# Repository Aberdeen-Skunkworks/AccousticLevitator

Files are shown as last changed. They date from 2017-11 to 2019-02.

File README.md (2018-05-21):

# Accoustic Levitator

A device for trapping and manipulating particles in three dimensions as well as the software to simulate these traps.

This Project is split into two distinct sections (1) The control software for the physical array, (2) The acoustic simulation to model the fields produced by this array.

The goal is to have a system that can self-calibrate where the control software can detect and automatically figure out where multiple acoustic arrays are in relation to each other, (Using the -> Aberdeen-Skunkworks/AccousticTracker project) It can then take this positional information and form acoustic traps at desired locations.

The files in the /eagle folder are PCB design files that use the Autodesk PCB design software Eagle which can be found here: https://www.autodesk.com/products/eagle/overview

The files in the /FPGA folder are the setup files that are running on the Field-Programable Gate Arrays that create the ultrasonic signals that are sent to the transducers.

# (1) Control software

# (2) Acoustic simulation

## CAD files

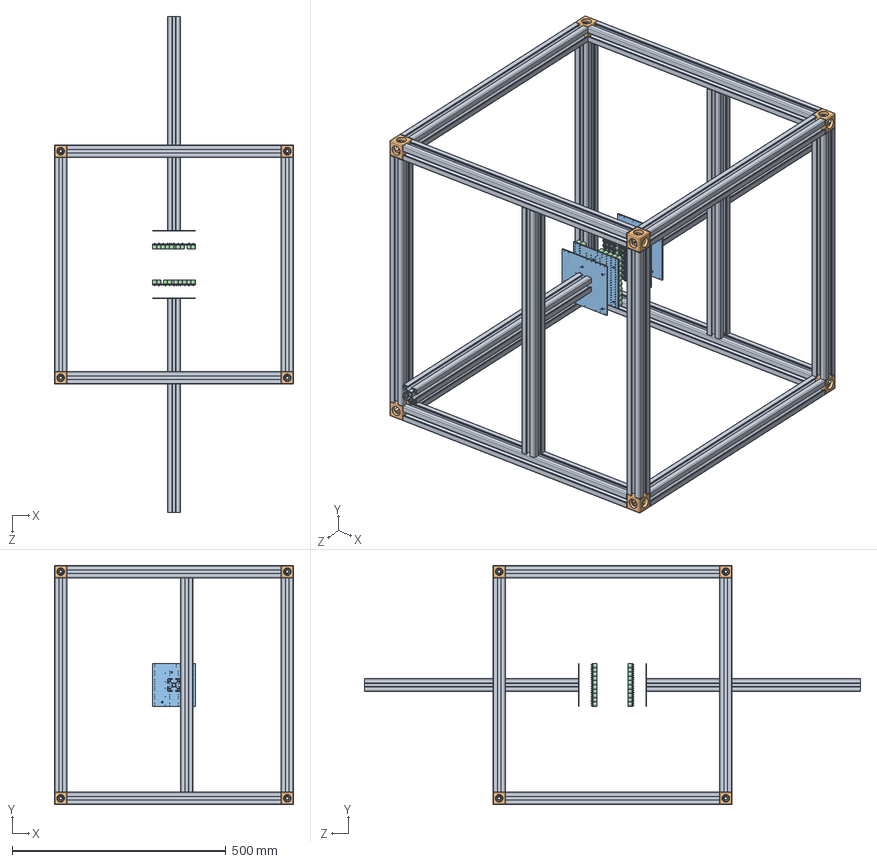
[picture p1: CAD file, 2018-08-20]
Moddeling_Files/Assembly of frame.SLDASM
560.0 x 560.0 x 1160.0 mm
30 mm al profile x 16
corner x 8
board x 4
Transducer x 176

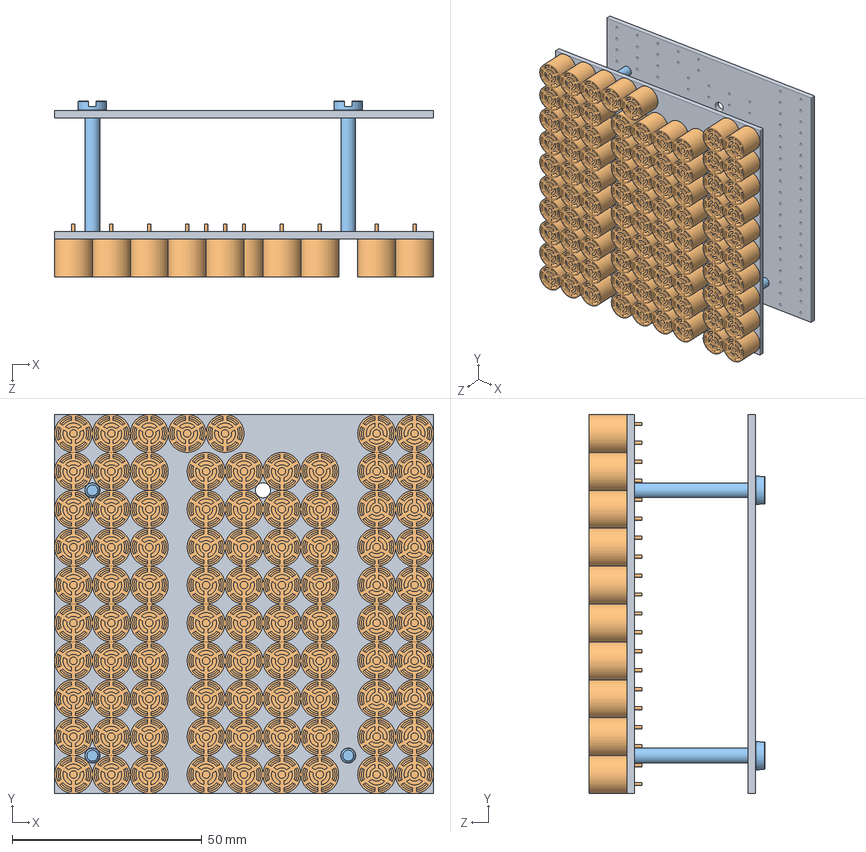
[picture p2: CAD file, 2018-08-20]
Moddeling_Files/Board and transducers.SLDASM
100.0 x 100.0 x 46.5 mm
board x 2
Transducer x 88
bolt x 3

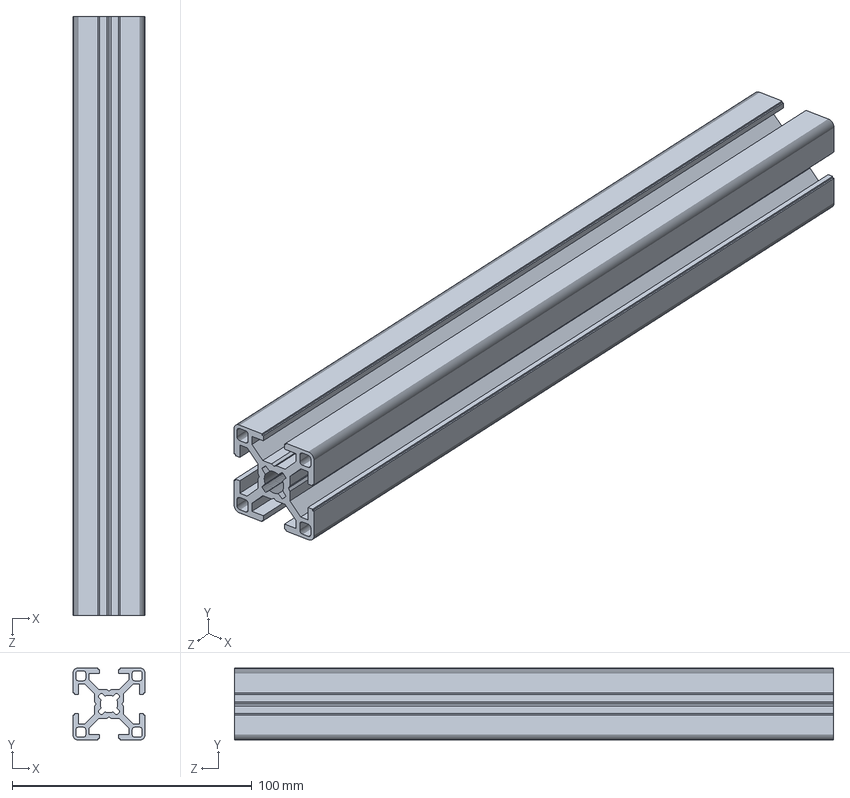
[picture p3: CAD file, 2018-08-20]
Moddeling_Files/Accurate 30 mm profile.SLDPRT
30.0 x 30.0 x 250.0 mm

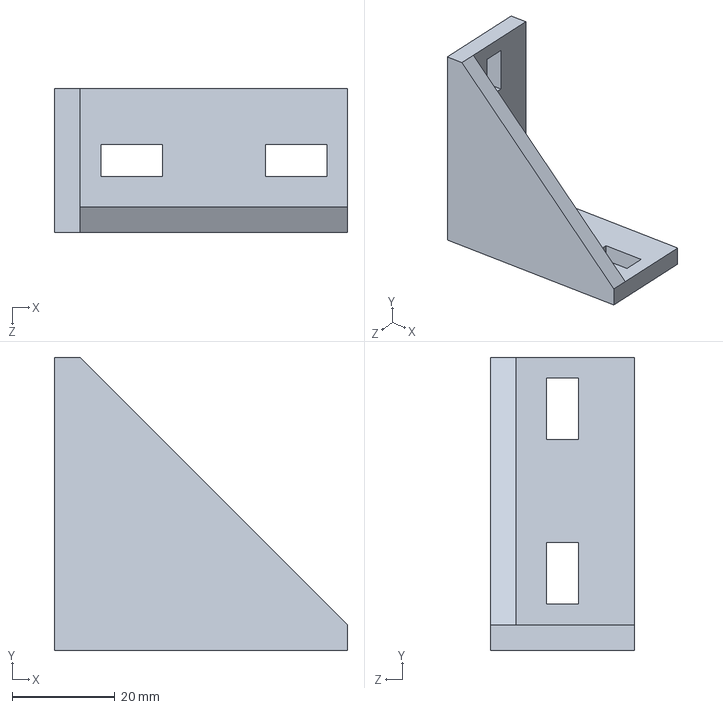
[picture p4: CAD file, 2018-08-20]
Moddeling_Files/angle bracket.SLDPRT
57.0 x 57.0 x 28.0 mm

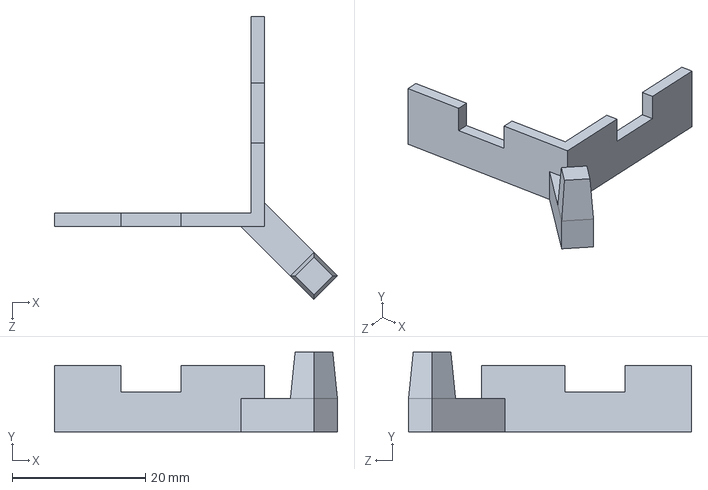
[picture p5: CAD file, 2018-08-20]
Moddeling_Files/hook2.SLDPRT
42.5 x 12.0 x 42.5 mm

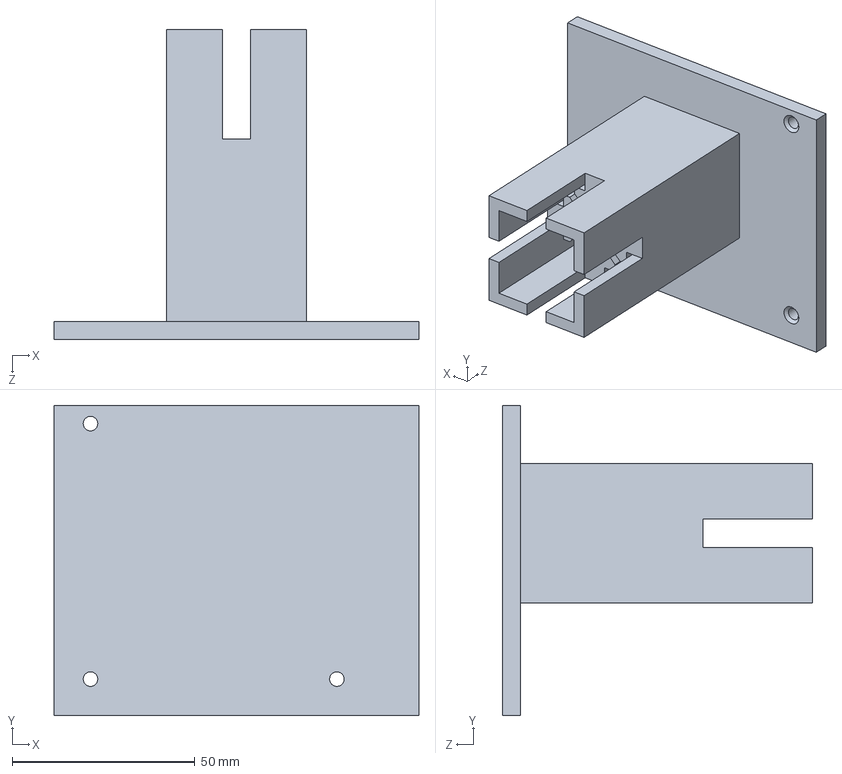
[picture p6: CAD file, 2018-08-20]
Moddeling_Files/board holder no tubes and thicker back.SLDPRT
100.0 x 85.0 x 85.0 mm

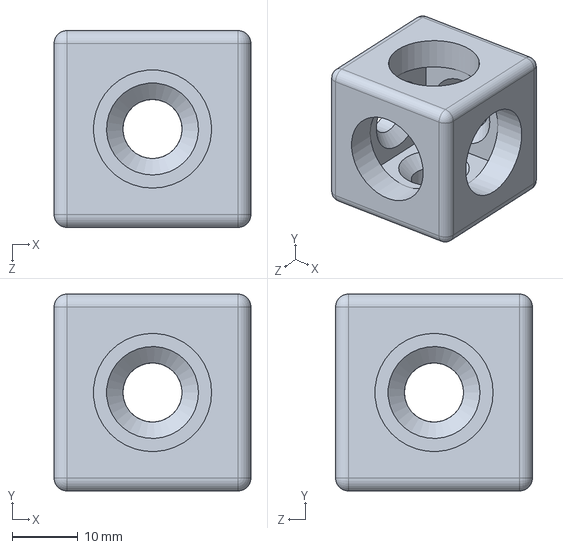
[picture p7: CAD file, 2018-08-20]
Moddeling_Files/corner.SLDPRT
30.0 x 30.0 x 30.0 mm

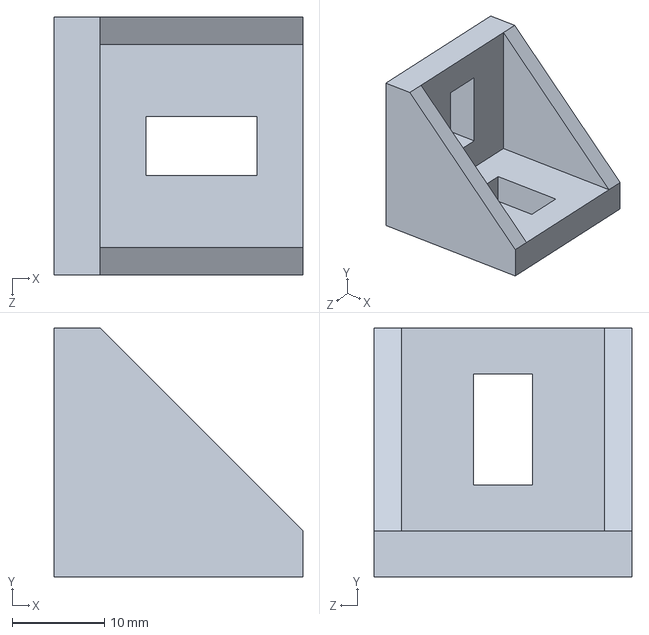
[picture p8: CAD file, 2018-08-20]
Moddeling_Files/corner_small.SLDPRT
27.0 x 27.0 x 28.0 mm

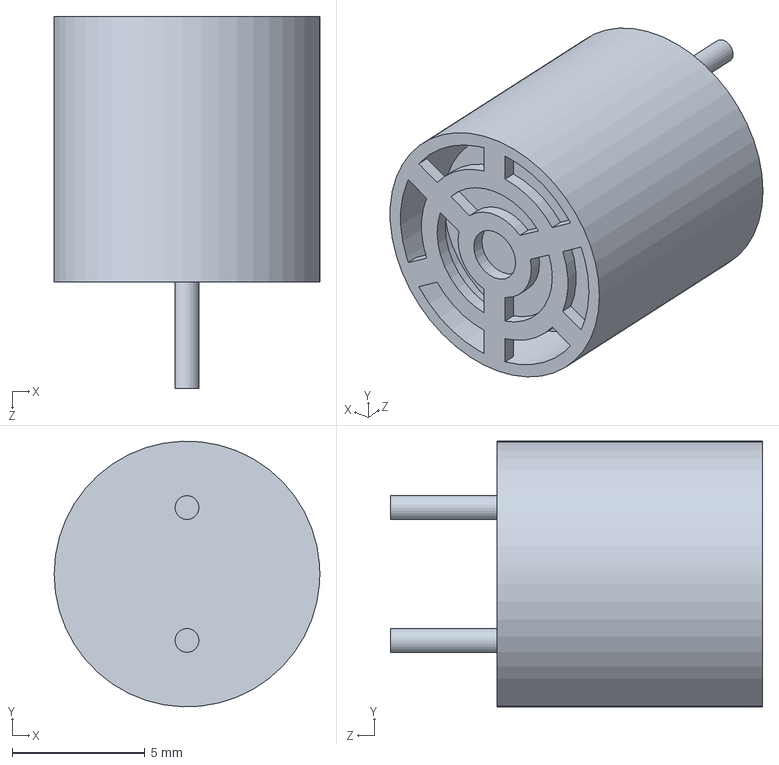
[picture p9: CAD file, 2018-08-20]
Moddeling_Files/Transducer.SLDPRT
10.0 x 9.99 x 14.0 mm

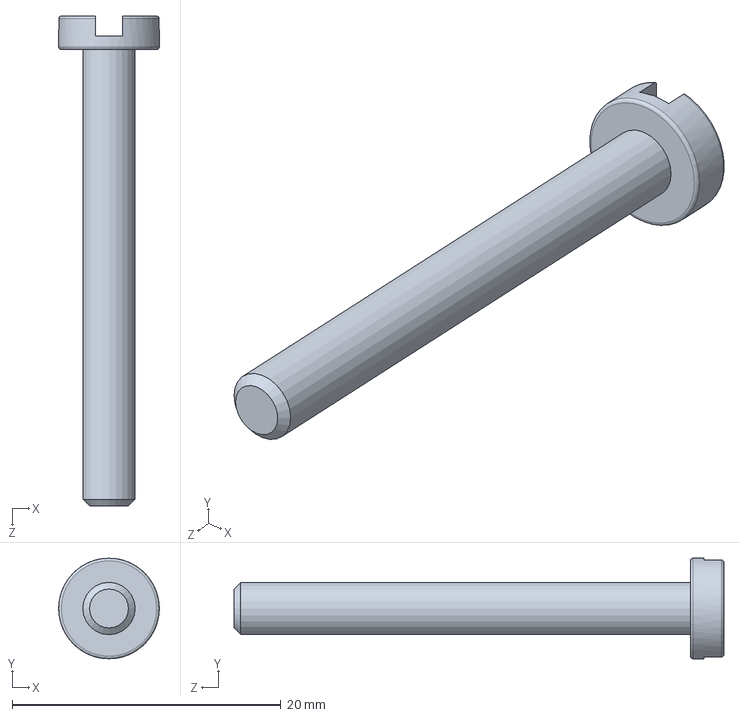
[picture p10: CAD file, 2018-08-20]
Moddeling_Files/bolt.SLDPRT
7.50 x 7.50 x 36.5 mm

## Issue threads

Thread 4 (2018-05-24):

Thread for Minor Syntax Problems

FourierSoiXa, 2018-05-24:
Hi guys,

I'd like to simply divide two numbers in Python 2.7 and get a 'double' output result,
float(A/B) does not seem to work, can someone point me into the right direction :)

Thanks, Fabio

toastedcrumpets, 2018-05-24:
If the numbers are integers, then you only get integer results from the
division. Promote one of them to float first i.e. float(a)/b or (a+0.0)/b
if you want to be obscure.

BTW, python 3 and later automatically promotes them when a integer divide
would lose information via truncation

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

FourierSoiXa, 2018-05-24:
That's great thanks! It works just fine like that:

`print 'The tested Number is a ' + str(tIndex) + ' with a probability of ' + str(float(tCount)/nPerfectMatch)`

Just working on recognizing some numbers and I'll try to get shapes done by the weekend. Files will be uploaded as soon as they are completed and commented

toastedcrumpets, 2018-05-24:
Great! Remember useful python commands like type(X) repr(X) and help(X).
Also, try dir(X) on objects too.

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

FourierSoiXa, 2018-05-27:
A little help is required with the return statements of functions:
I'd like to calculate the center of an image and return the respective x and y coordinates to be used in different functions and the function seems to work just fine:

`def centerImage(filePath):
    iCenter = Image.open(filePath)
    iArray = iCenter.load()
    iDisplay = np.array(iCenter)
    (X,Y) = iCenter.size
    matrix = np.zeros((X,Y))
    # Create a matrix containing 1's for every pixel of the image
    for x in range(X):
        for y in range(X):
            matrix[x,y] = iArray[(x,y)] != (255,255,255)
    matrix = matrix/np.sum(np.sum(matrix))

    # Compute marginal distribution and expected values

    dx = np.sum(matrix,1)
    dy = np.sum(matrix,0)

    expX = np.sum(dx*np.arange(X))
    expY = np.sum(dy*np.arange(Y))

    # Displays Examples of the center of the image

    fig = plt.figure()
    plt.imshow(iDisplay)
    plt.plot(expX, expY, marker='s', linestyle='-', color='r')
    plt.show()
    return [expX,expY] `

For some reason I can't make the return statement work/ cannot assign the returned values to a new variable. I tired:

`comX = centerImage
comX = centerImage[0]
print comX(0)`

Help would be greatly appreciated :) Thanks a lot in advance

NiallMacD, 2018-05-27:
Not entirely sure what your code is doing or supposed to do. Firstly I am assuming when you loop over x and y that "for y in range(X):" should be "for y in range(Y):". Other than that see below how you call your function while passing it "1 required positional argument: 'filePath' " making a variable equal to the called function will set that variable to whatever is returned by that function.
Hope this helps, if you could explain what its trying to do that would be ace, i tried it with a blank image and it set a random square of it red in the output.

```ruby
import numpy as np
from PIL import Image
import matplotlib.pyplot as plt

def centerImage(filePath):
    iCenter = Image.open(filePath)
    iArray = iCenter.load()
    iDisplay = np.array(iCenter)
    (X,Y) = iCenter.size
    matrix = np.zeros((X,Y))

    # Create a matrix containing 1's for every pixel of the image
    for x in range(X):
        for y in range(Y):
            matrix[x,y] = iArray[(x,y)] != (255,255,255)
            matrix = matrix/np.sum(np.sum(matrix))

    # Compute marginal distribution and expected values

    dx = np.sum(matrix,1)
    dy = np.sum(matrix,0)

    expX = np.sum(dx*np.arange(X))
    expY = np.sum(dy*np.arange(Y))

    # Displays Examples of the center of the image

    fig = plt.figure()
    plt.imshow(iDisplay)
    plt.plot(expX, expY, marker='s', linestyle='-', color='r')
    plt.show()
    return [expX,expY]

# Pass the function the location of the test image
where_you_want_output_to_go = centerImage( "test_image.png" )

# print the x, y co-ordinates
print(where_you_want_output_to_go)

```

FourierSoiXa, 2018-05-27:
Hi Niall,
aaaaw that makes perfect sense.... whenever I tried to assign the returned values to a variable I didnt actually include the filePath argument. I guess I've been staring at the screen for a little too long.

Sorry for not including the import statements, that would have made it a little more clear.
The function is computing the center of the image based on the distribution of non-white pixels. I tried to recognize numbers with a program I'm working on but the problem I faced was that, as soon as the number was a little displaced, my program would predict a completely different number.
That's why I want to center the image first. Maybe the next task would be including rotation etc but just now I'm far away from that.

Try another image that is not entirely symetrical :) I'll upload a fully commented code in a day or two into the particle recognition thread, just now I'm not even sure whether the stuff I wrote is actually working.

Thanks a lot :)

toastedcrumpets, 2018-05-28:
With return statements and multiple values, you can do this (which is a bit neater)
`
def f():
  return 1,2,3,4
a,b,c,d = f()
 `
This returns the values as a tuple rather than a list. They work the same, but in theory a tuple is faster as its a fixed size.

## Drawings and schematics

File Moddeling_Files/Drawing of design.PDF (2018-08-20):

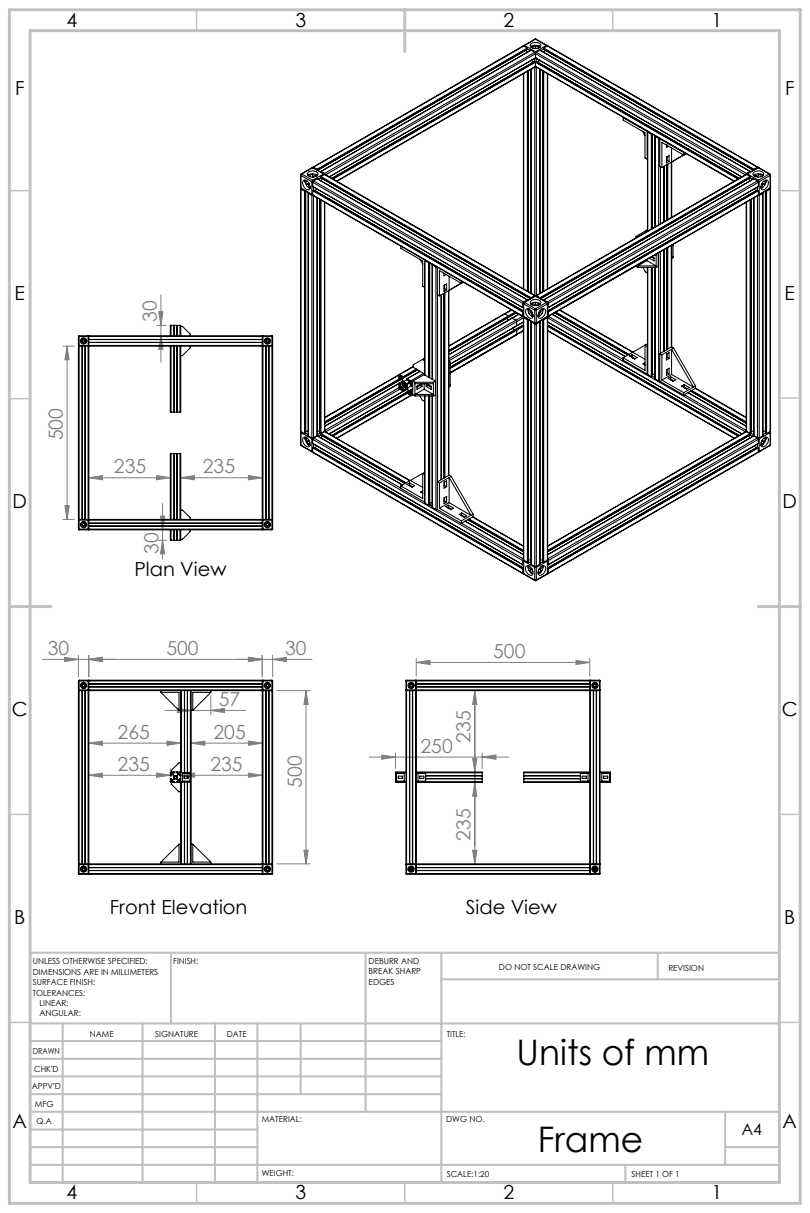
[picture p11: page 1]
Front Elevation; Side View; Plan View; FINISH:; DEBURR AND; BREAK SHARP; DO NOT SCALE DRAWING; REVISION; SCALE:1:20; SHEET 1 OF 1

UNLESS OTHERWISE SPECIFIED:
DIMENSIONS ARE IN MILLIMETERS
SURFACE FINISH:
TOLERANCES:
LINEAR:
ANGULAR:

NAME | SIGNATURE | DATE | | | | TITLE: Units of mm

DRAWN
CHK'D
APPV'D
MFG
Q.A | | | | MATERIAL: | DWG NO. Frame | A4

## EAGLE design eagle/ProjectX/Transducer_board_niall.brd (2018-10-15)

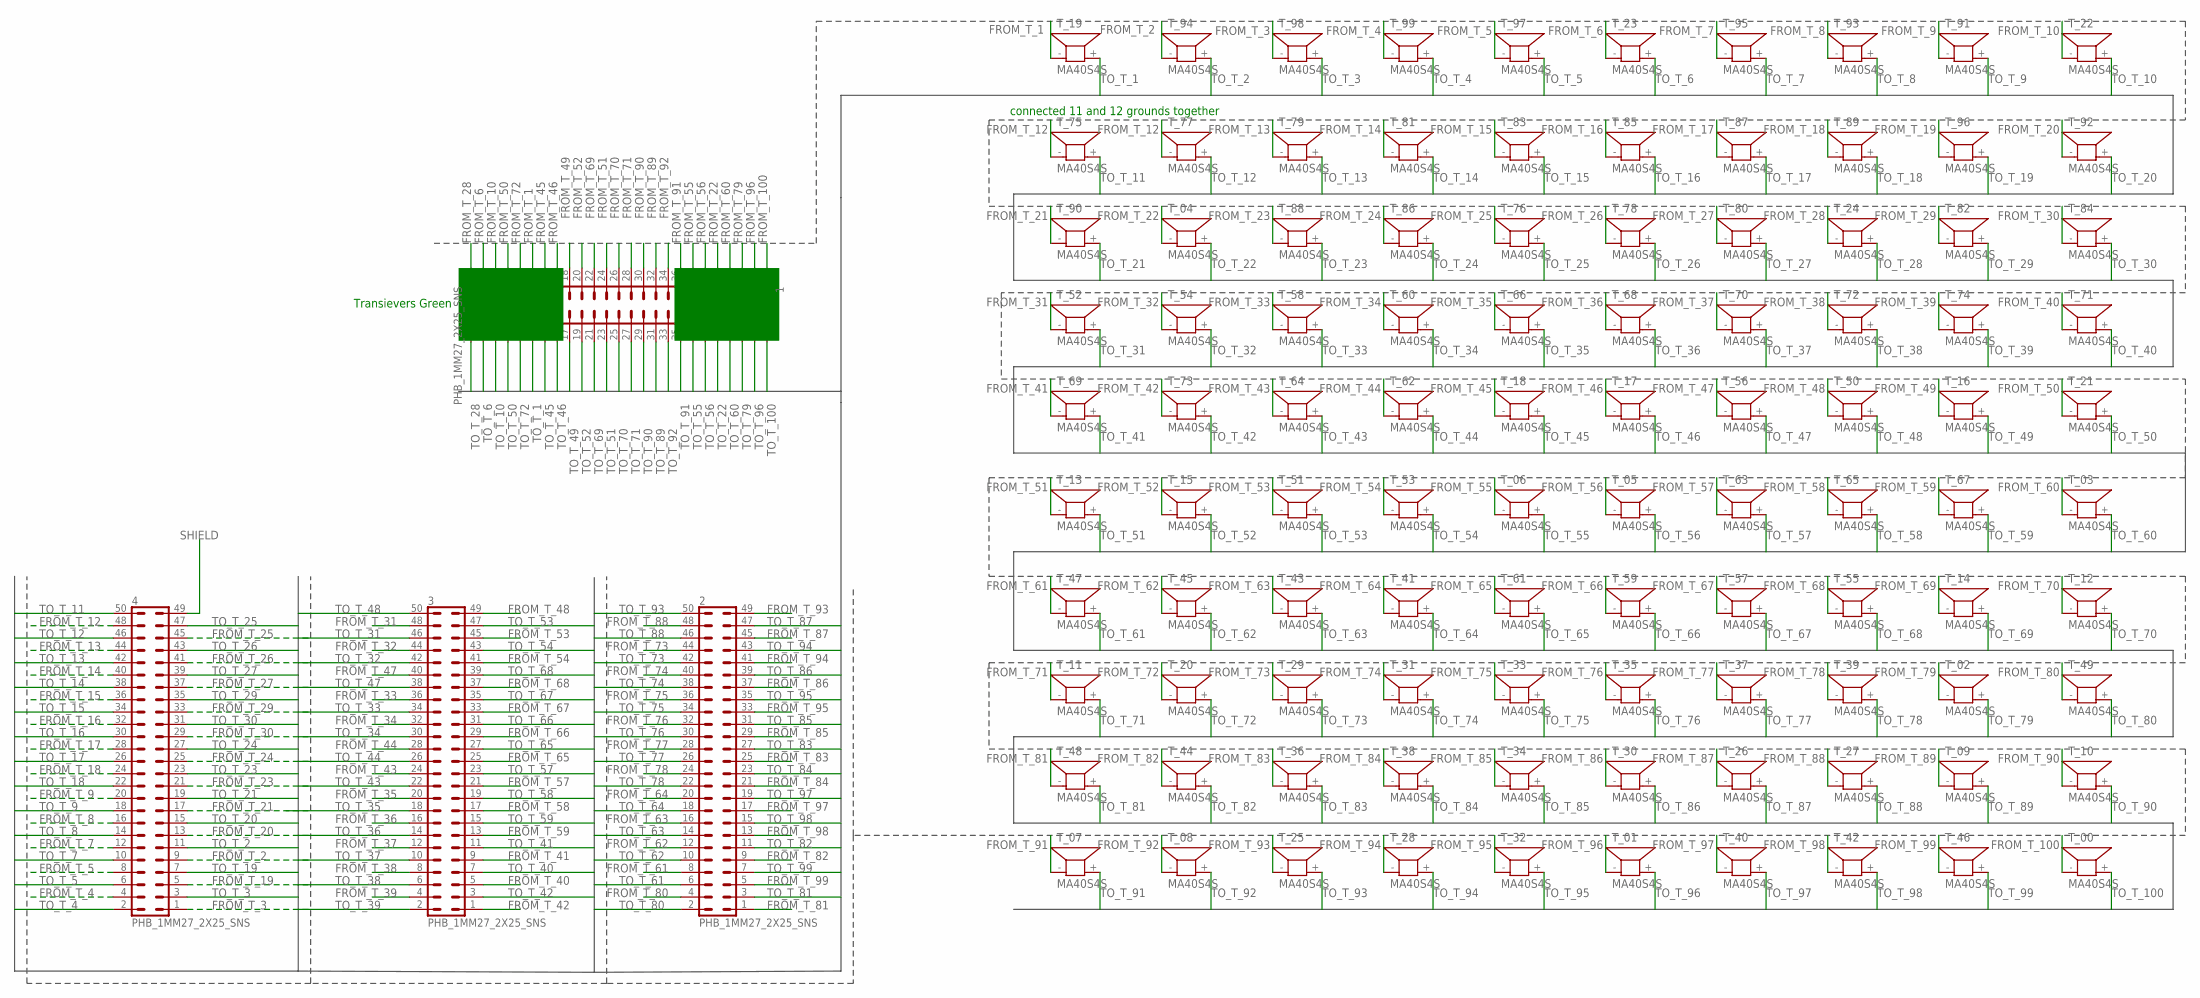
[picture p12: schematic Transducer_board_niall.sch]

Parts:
1, 2, 3, 4: PHB_1MM27_2X25_SNS
T_00, T_01, T_02, T_03, T_04, T_05, T_06, T_07, T_08, T_09, T_10, T_11, T_12, T_13, T_14, T_15, T_16, T_17, T_18, T_19, T_20, T_21, T_22, T_23, T_24, T_25, T_26, T_27, T_28, T_29, T_30, T_31, T_32, T_33, T_34, T_35, T_36, T_37, T_38, T_39, T_40, T_41, T_42, T_43, T_44, T_45, T_46, T_47, T_48, T_49, T_50, T_51, T_52, T_53, T_54, T_55, T_56, T_57, T_58, T_59, T_60, T_61, T_62, T_63, T_64, T_65, T_66, T_67, T_68, T_69, T_70, T_71, T_72, T_73, T_74, T_75, T_76, T_77, T_78, T_79, T_80, T_81, T_82, T_83, T_84, T_85, T_86, T_87, T_88, T_89, T_90, T_91, T_92, T_93, T_94, T_95, T_96, T_97, T_98, T_99: MA40S4S; MA40

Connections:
FROM_T_1: 1.12, T_19.- (1)
FROM_T_2: 4.9, T_94.- (1)
FROM_T_3: 4.1, T_98.- (1)
FROM_T_4: 4.4, T_99.- (1)
FROM_T_5: 4.8, T_97.- (1)
FROM_T_6: 1.4, T_23.- (1)
FROM_T_7: 4.12, T_95.- (1)
FROM_T_8: 4.16, T_93.- (1)
FROM_T_9: 4.20, T_91.- (1)
FROM_T_10: 1.6, T_22.- (1)
FROM_T_12: 4.48, T_75.- (1), T_77.- (1)
FROM_T_13: 4.44, T_79.- (1)
FROM_T_14: 4.40, T_81.- (1)
FROM_T_15: 4.36, T_83.- (1)
FROM_T_16: 4.32, T_85.- (1)
FROM_T_17: 4.28, T_87.- (1)
FROM_T_18: 4.24, T_89.- (1)
FROM_T_19: 4.5, T_96.- (1)
FROM_T_20: 4.13, T_92.- (1)
FROM_T_21: 4.17, T_90.- (1)
FROM_T_22: 1.42, T_04.- (1)
FROM_T_23: 4.21, T_88.- (1)
FROM_T_24: 4.25, T_86.- (1)
FROM_T_25: 4.45, T_76.- (1)
FROM_T_26: 4.41, T_78.- (1)
FROM_T_27: 4.37, T_80.- (1)
FROM_T_28: 1.2, T_24.- (1)
FROM_T_29: 4.33, T_82.- (1)
FROM_T_30: 4.29, T_84.- (1)
FROM_T_31: 3.48, T_52.- (1)
FROM_T_32: 3.44, T_54.- (1)
FROM_T_33: 3.36, T_58.- (1)
FROM_T_34: 3.32, T_60.- (1)
FROM_T_35: 3.20, T_66.- (1)
FROM_T_36: 3.16, T_68.- (1)
FROM_T_37: 3.12, T_70.- (1)
FROM_T_38: 3.8, T_72.- (1)
FROM_T_39: 3.4, T_74.- (1)
FROM_T_40: 3.5, T_71.- (1)
FROM_T_41: 3.9, T_69.- (1)
FROM_T_42: 3.1, T_73.- (1)
FROM_T_43: 3.24, T_64.- (1)
FROM_T_44: 3.28, T_62.- (1)
FROM_T_45: 1.14, T_18.- (1)
FROM_T_46: 1.16, T_17.- (1)
FROM_T_47: 3.40, T_56.- (1)
FROM_T_48: 3.49, T_50.- (1)
FROM_T_49: 1.18, T_16.- (1)
FROM_T_50: 1.8, T_21.- (1)
FROM_T_51: 1.24, T_13.- (1)
FROM_T_52: 1.20, T_15.- (1)
FROM_T_53: 3.45, T_51.- (1)
FROM_T_54: 3.41, T_53.- (1)
FROM_T_55: 1.38, T_06.- (1)
FROM_T_56: 1.40, T_05.- (1)
FROM_T_57: 3.21, T_63.- (1)
FROM_T_58: 3.17, T_65.- (1)
FROM_T_59: 3.13, T_67.- (1)
FROM_T_60: 1.44, T_03.- (1)
FROM_T_61: 2.8, T_47.- (1)
FROM_T_62: 2.12, T_45.- (1)
FROM_T_63: 2.16, T_43.- (1)
FROM_T_64: 2.20, T_41.- (1)
FROM_T_65: 3.25, T_61.- (1)
FROM_T_66: 3.29, T_59.- (1)
FROM_T_67: 3.33, T_57.- (1)
FROM_T_68: 3.37, T_55.- (1)
FROM_T_69: 1.22, T_14.- (1)
FROM_T_70: 1.26, T_12.- (1)
FROM_T_71: 1.28, T_11.- (1)
FROM_T_72: 1.10, T_20.- (1)
FROM_T_73: 2.44, T_29.- (1)
FROM_T_74: 2.40, T_31.- (1)
FROM_T_75: 2.36, T_33.- (1)
FROM_T_76: 2.32, T_35.- (1)
FROM_T_77: 2.28, T_37.- (1)
FROM_T_78: 2.24, T_39.- (1)
FROM_T_79: 1.46, T_02.- (1)
FROM_T_80: 2.4, T_49.- (1)
FROM_T_81: 2.1, T_48.- (1)
FROM_T_82: 2.9, T_44.- (1)
FROM_T_83: 2.25, T_36.- (1)
FROM_T_84: 2.21, T_38.- (1)
FROM_T_85: 2.29, T_34.- (1)
FROM_T_86: 2.37, T_30.- (1)
FROM_T_87: 2.45, T_26.- (1)
FROM_T_88: 2.48, T_27.- (1)
FROM_T_89: 1.32, T_09.- (1)
FROM_T_90: 1.30, T_10.- (1)
FROM_T_91: 1.36, T_07.- (1)
FROM_T_92: 1.34, T_08.- (1)
FROM_T_93: 2.49, T_25.- (1)
FROM_T_94: 2.41, T_28.- (1)
FROM_T_95: 2.33, T_32.- (1)
FROM_T_96: 1.48, T_01.- (1)
FROM_T_97: 2.17, T_40.- (1)
FROM_T_98: 2.13, T_42.- (1)
FROM_T_99: 2.5, T_46.- (1)
FROM_T_100: 1.50, T_00.- (1)
SHIELD: 4.49
TO_T_1: 1.11, T_19.+ (2)
TO_T_2: 4.11, T_94.+ (2)
TO_T_3: 4.3, T_98.+ (2)
TO_T_4: 4.2, T_99.+ (2)
TO_T_5: 4.6, T_97.+ (2)
TO_T_6: 1.3, T_23.+ (2)
TO_T_7: 4.10, T_95.+ (2)
TO_T_8: 4.14, T_93.+ (2)
TO_T_9: 4.18, T_91.+ (2)
TO_T_10: 1.5, T_22.+ (2)
TO_T_11: 4.50, T_75.+ (2)
TO_T_12: 4.46, T_77.+ (2)
TO_T_13: 4.42, T_79.+ (2)
TO_T_14: 4.38, T_81.+ (2)
TO_T_15: 4.34, T_83.+ (2)
TO_T_16: 4.30, T_85.+ (2)
TO_T_17: 4.26, T_87.+ (2)
TO_T_18: 4.22, T_89.+ (2)
TO_T_19: 4.7, T_96.+ (2)
TO_T_20: 4.15, T_92.+ (2)
TO_T_21: 4.19, T_90.+ (2)
TO_T_22: 1.41, T_04.+ (2)
TO_T_23: 4.23, T_88.+ (2)
TO_T_24: 4.27, T_86.+ (2)
TO_T_25: 4.47, T_76.+ (2)
TO_T_26: 4.43, T_78.+ (2)
TO_T_27: 4.39, T_80.+ (2)
TO_T_28: 1.1, T_24.+ (2)
TO_T_29: 4.35, T_82.+ (2)
TO_T_30: 4.31, T_84.+ (2)
TO_T_31: 3.46, T_52.+ (2)
TO_T_32: 3.42, T_54.+ (2)
TO_T_33: 3.34, T_58.+ (2)
TO_T_34: 3.30, T_60.+ (2)
TO_T_35: 3.18, T_66.+ (2)
TO_T_36: 3.14, T_68.+ (2)
TO_T_37: 3.10, T_70.+ (2)
TO_T_38: 3.6, T_72.+ (2)
TO_T_39: 3.2, T_74.+ (2)
TO_T_40: 3.7, T_71.+ (2)
TO_T_41: 3.11, T_69.+ (2)
TO_T_42: 3.3, T_73.+ (2)
TO_T_43: 3.22, T_64.+ (2)
TO_T_44: 3.26, T_62.+ (2)
TO_T_45: 1.13, T_18.+ (2)
TO_T_46: 1.15, T_17.+ (2)
TO_T_47: 3.38, T_56.+ (2)
TO_T_48: 3.50, T_50.+ (2)
TO_T_49: 1.17, T_16.+ (2)
TO_T_50: 1.7, T_21.+ (2)
TO_T_51: 1.23, T_13.+ (2)
TO_T_52: 1.19, T_15.+ (2)
TO_T_53: 3.47, T_51.+ (2)
TO_T_54: 3.43, T_53.+ (2)
TO_T_55: 1.37, T_06.+ (2)
TO_T_56: 1.39, T_05.+ (2)
TO_T_57: 3.23, T_63.+ (2)
TO_T_58: 3.19, T_65.+ (2)
TO_T_59: 3.15, T_67.+ (2)
TO_T_60: 1.43, T_03.+ (2)
TO_T_61: 2.6, T_47.+ (2)
TO_T_62: 2.10, T_45.+ (2)
TO_T_63: 2.14, T_43.+ (2)
TO_T_64: 2.18, T_41.+ (2)
TO_T_65: 3.27, T_61.+ (2)
TO_T_66: 3.31, T_59.+ (2)
TO_T_67: 3.35, T_57.+ (2)
TO_T_68: 3.39, T_55.+ (2)
TO_T_69: 1.21, T_14.+ (2)
TO_T_70: 1.25, T_12.+ (2)
TO_T_71: 1.27, T_11.+ (2)
TO_T_72: 1.9, T_20.+ (2)
TO_T_73: 2.42, T_29.+ (2)
TO_T_74: 2.38, T_31.+ (2)
TO_T_75: 2.34, T_33.+ (2)
TO_T_76: 2.30, T_35.+ (2)
TO_T_77: 2.26, T_37.+ (2)
TO_T_78: 2.22, T_39.+ (2)
TO_T_79: 1.45, T_02.+ (2)
TO_T_80: 2.2, T_49.+ (2)
TO_T_81: 2.3, T_48.+ (2)
TO_T_82: 2.11, T_44.+ (2)
TO_T_83: 2.27, T_36.+ (2)
TO_T_84: 2.23, T_38.+ (2)
TO_T_85: 2.31, T_34.+ (2)
TO_T_86: 2.39, T_30.+ (2)
TO_T_87: 2.47, T_26.+ (2)
TO_T_88: 2.46, T_27.+ (2)
TO_T_89: 1.31, T_09.+ (2)
TO_T_90: 1.29, T_10.+ (2)
TO_T_91: 1.35, T_07.+ (2)
TO_T_92: 1.33, T_08.+ (2)
TO_T_93: 2.50, T_25.+ (2)
TO_T_94: 2.43, T_28.+ (2)
TO_T_95: 2.35, T_32.+ (2)
TO_T_96: 1.47, T_01.+ (2)
TO_T_97: 2.19, T_40.+ (2)
TO_T_98: 2.15, T_42.+ (2)
TO_T_99: 2.7, T_46.+ (2)
TO_T_100: 1.49, T_00.+ (2)

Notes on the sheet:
Transievers Green
connected 11 and 12 grounds together

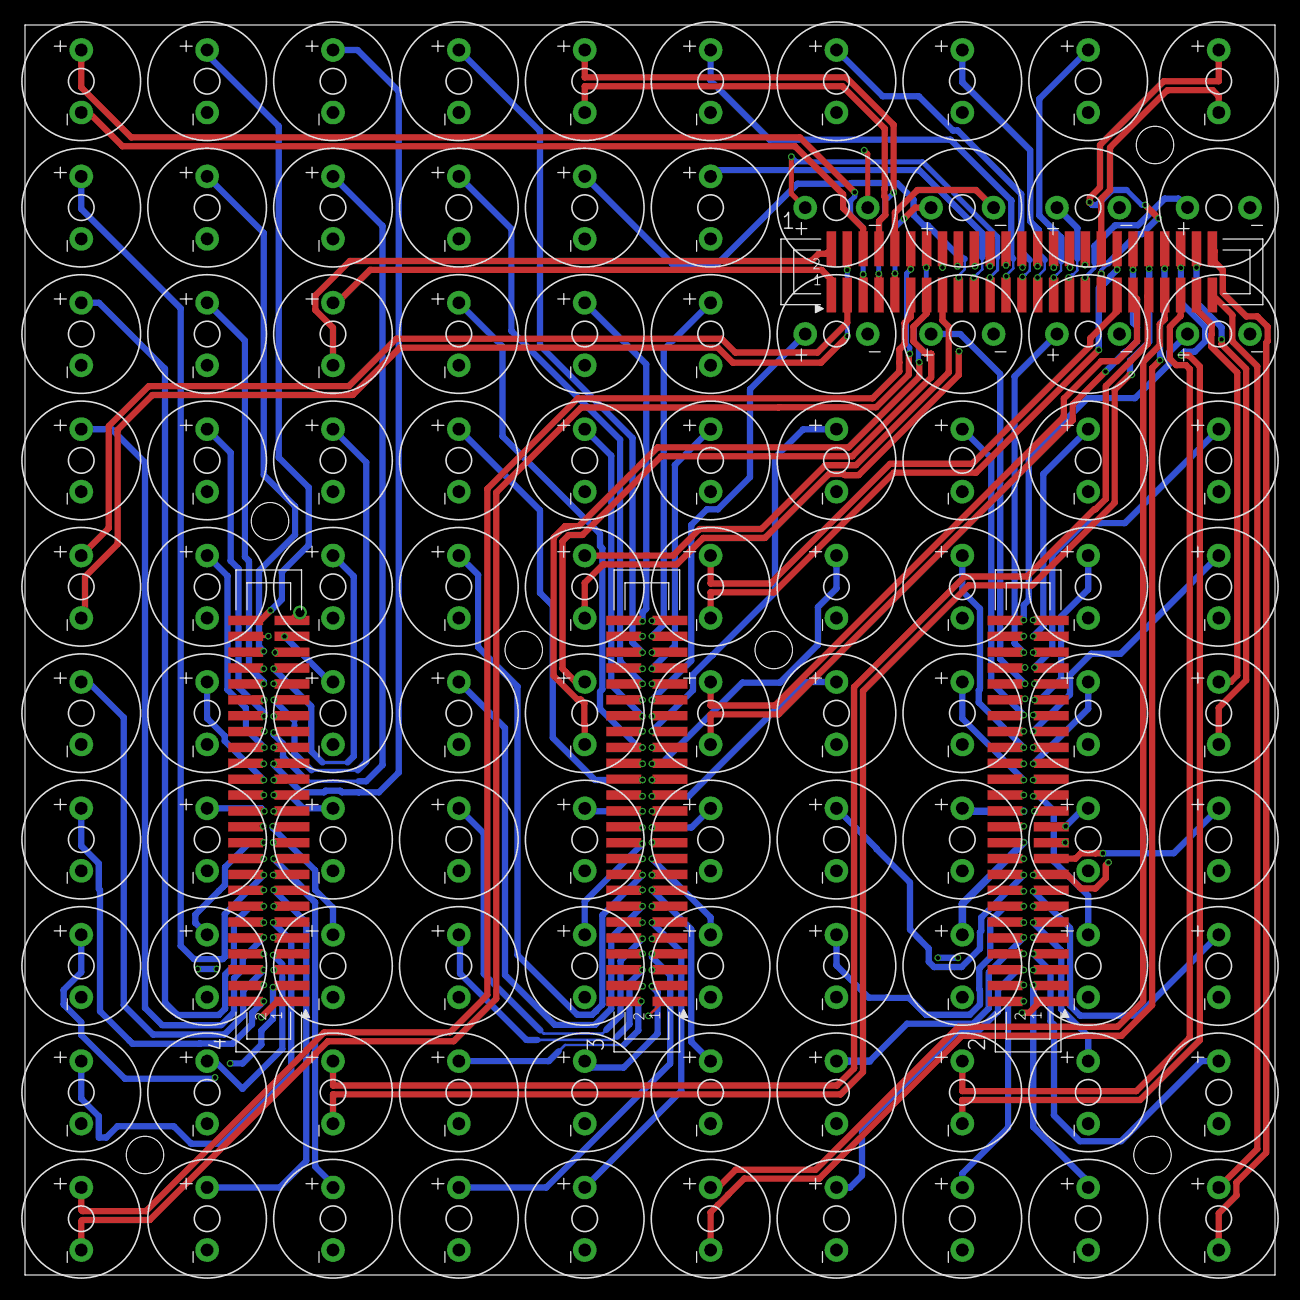
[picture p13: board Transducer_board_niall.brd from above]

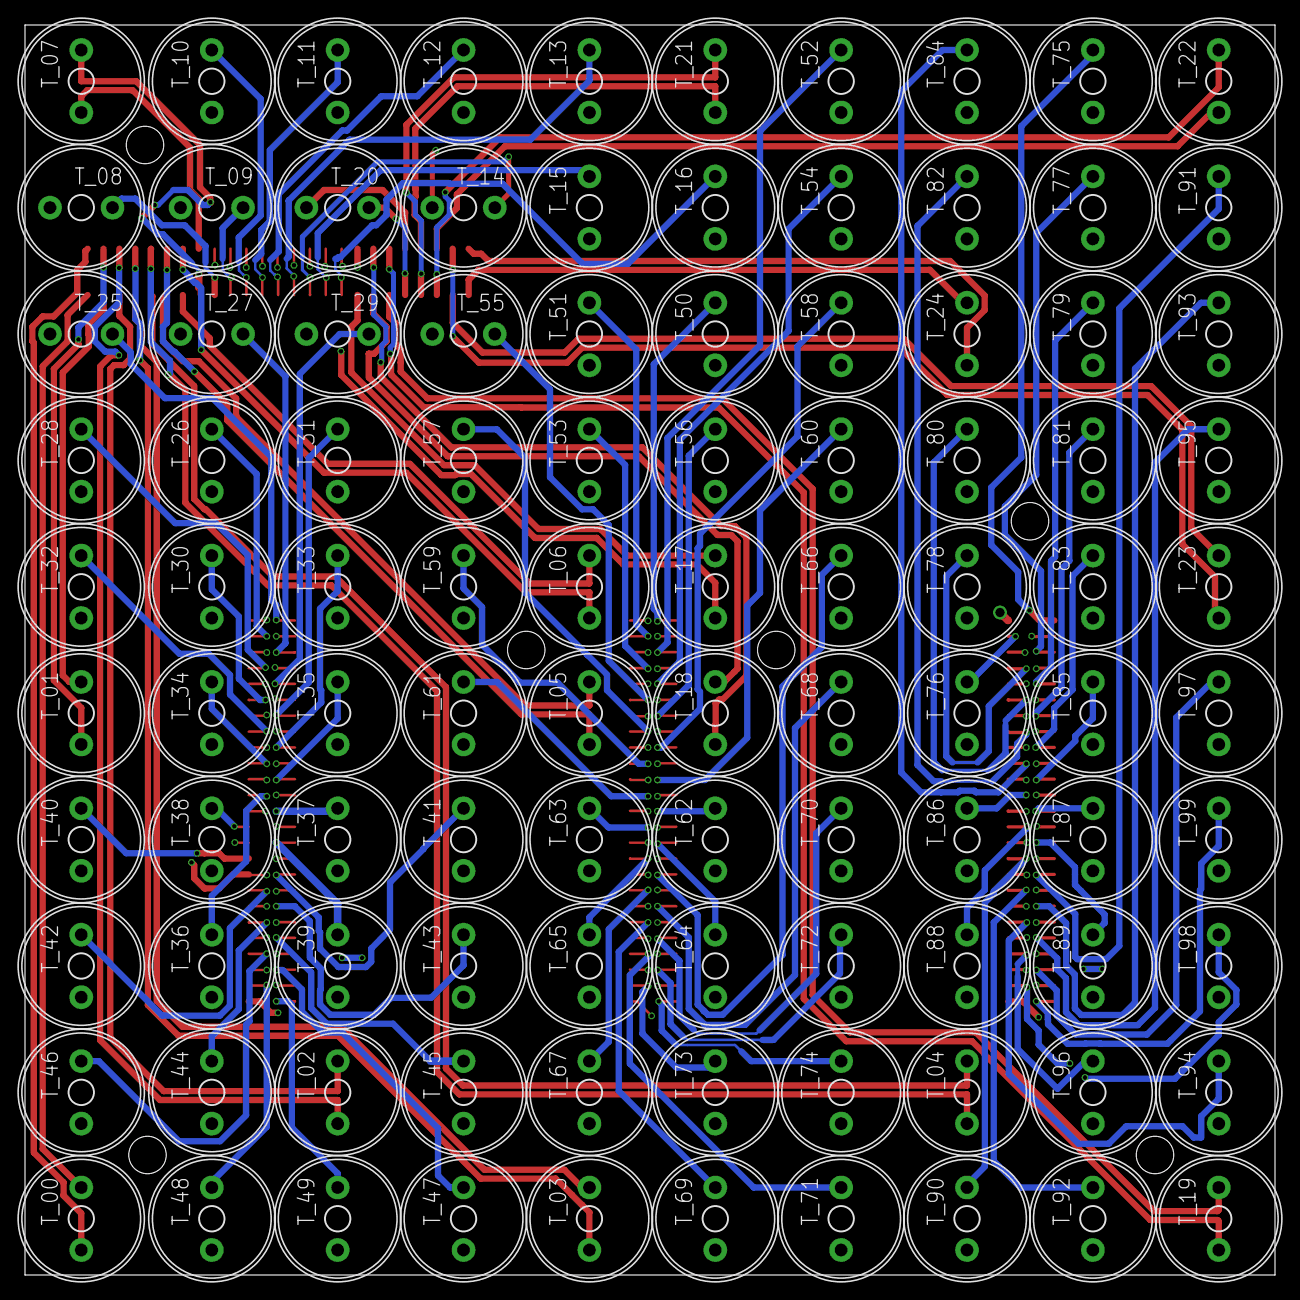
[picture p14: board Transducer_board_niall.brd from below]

Board: 4 copper layers, 100.0 x 100.0 mm, 104 parts (100 on the bottom side), 199 nets.

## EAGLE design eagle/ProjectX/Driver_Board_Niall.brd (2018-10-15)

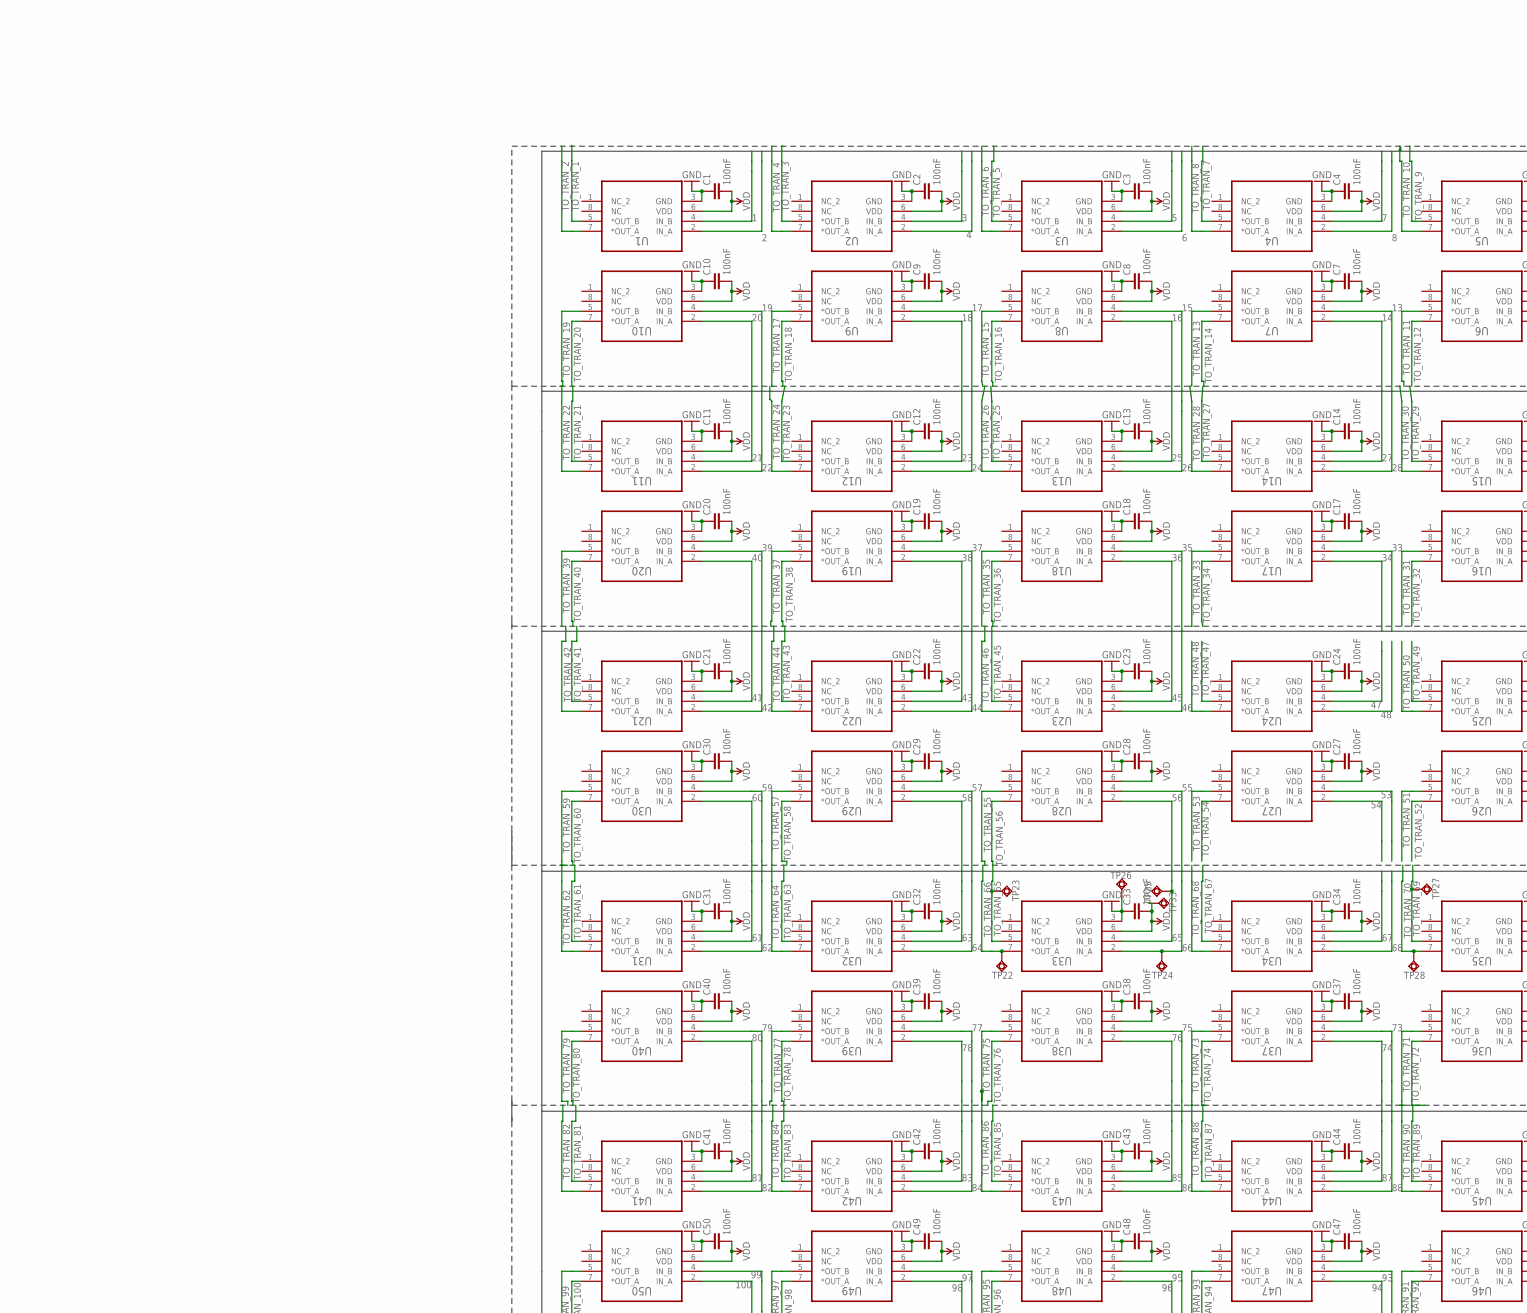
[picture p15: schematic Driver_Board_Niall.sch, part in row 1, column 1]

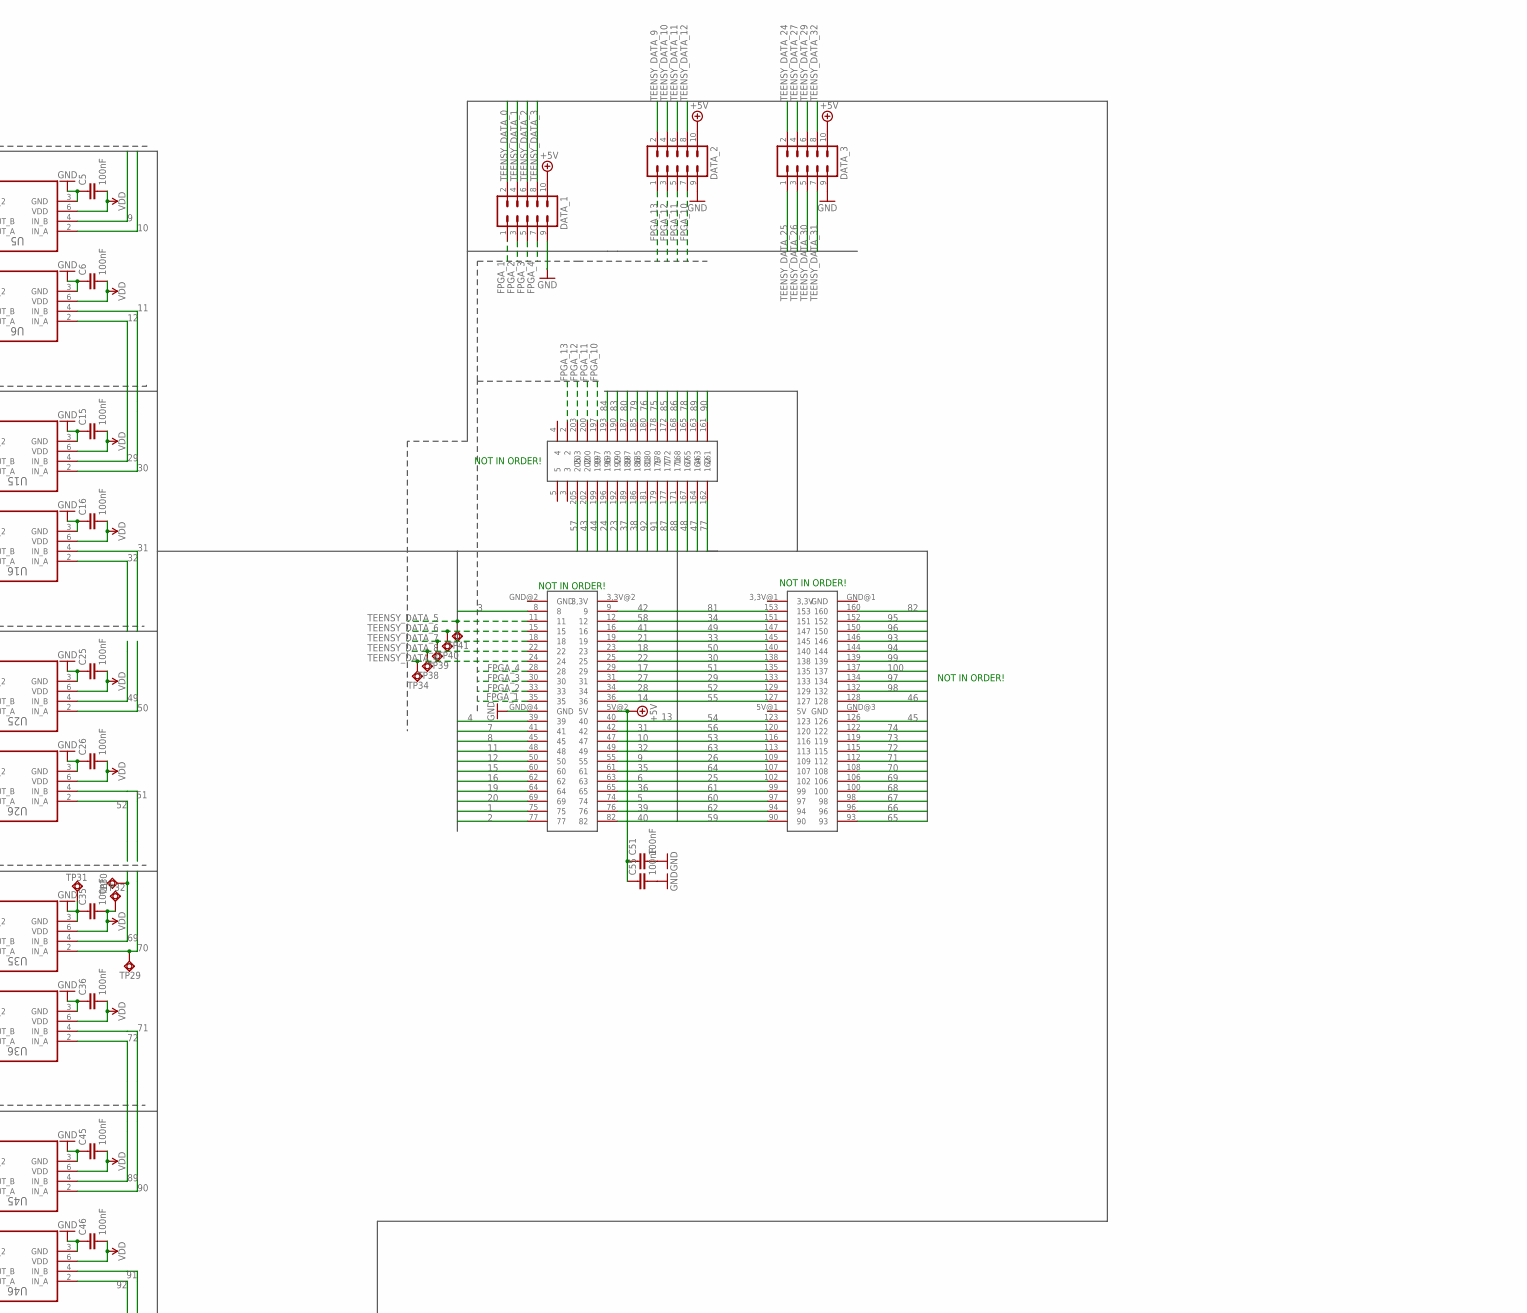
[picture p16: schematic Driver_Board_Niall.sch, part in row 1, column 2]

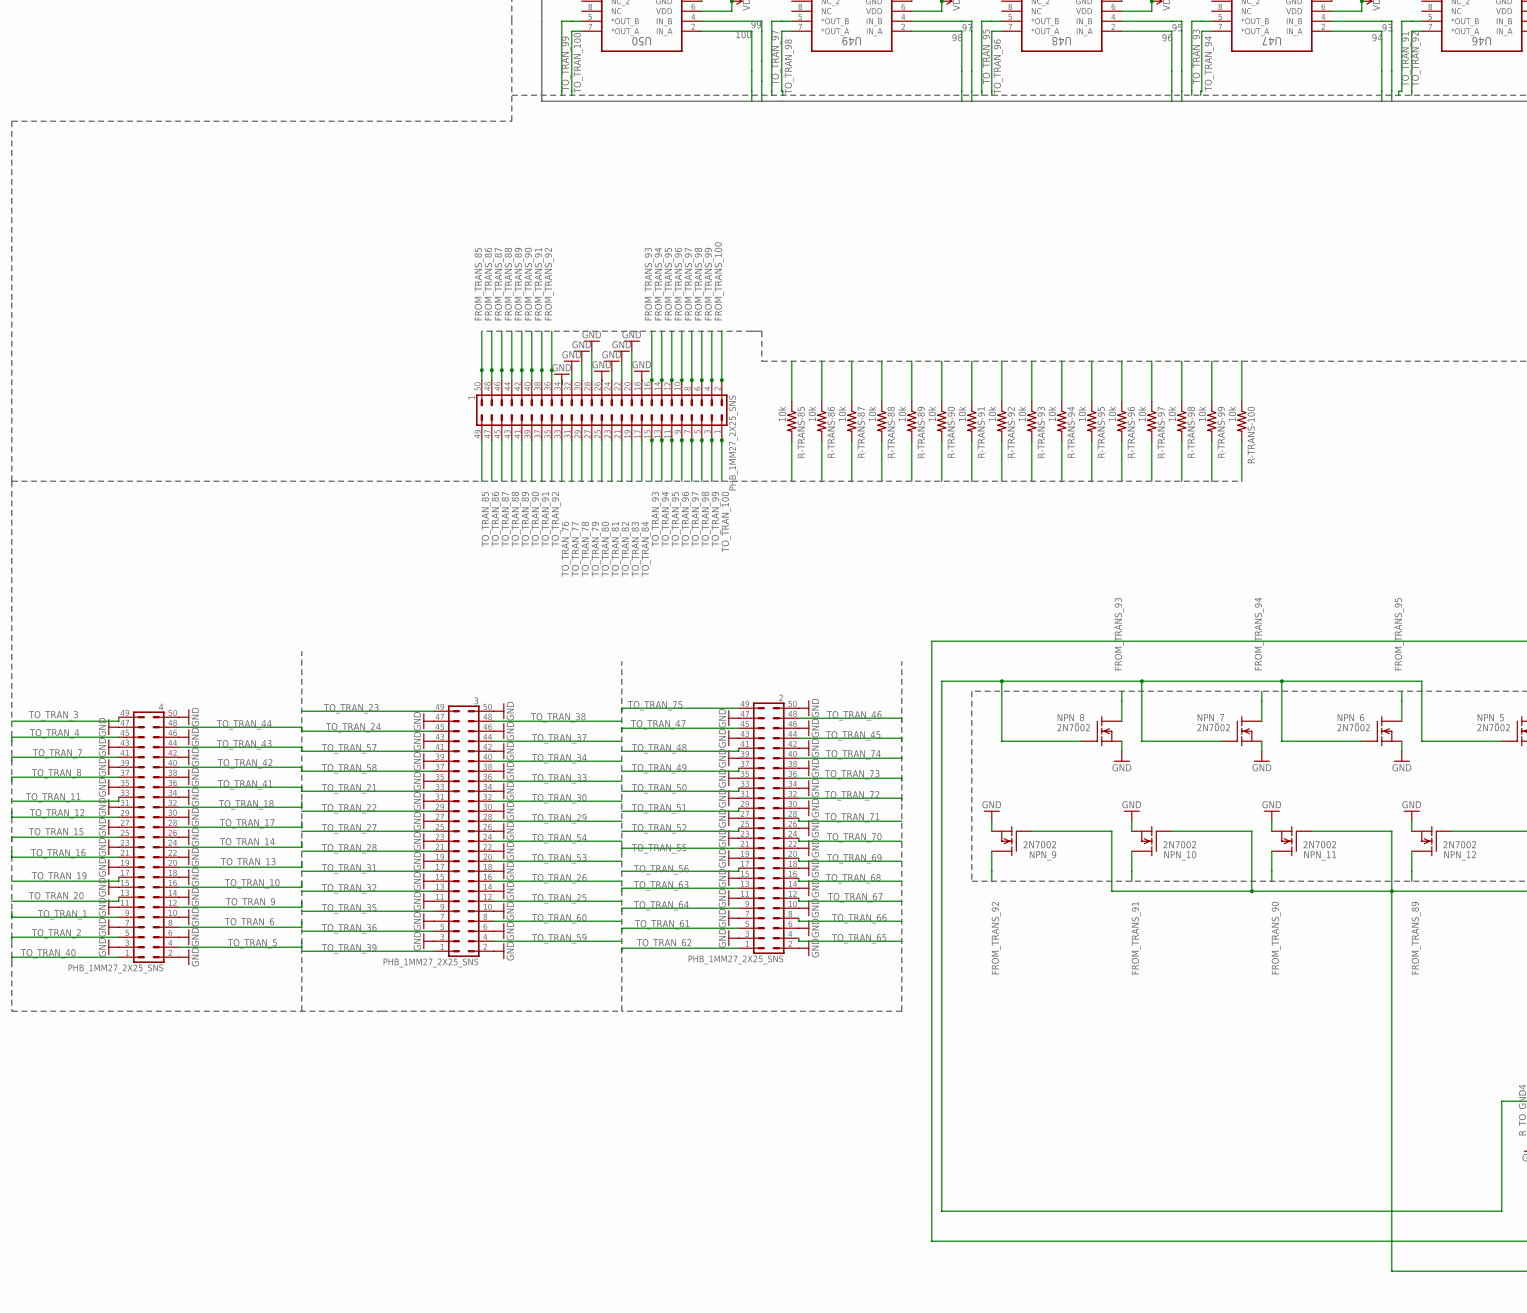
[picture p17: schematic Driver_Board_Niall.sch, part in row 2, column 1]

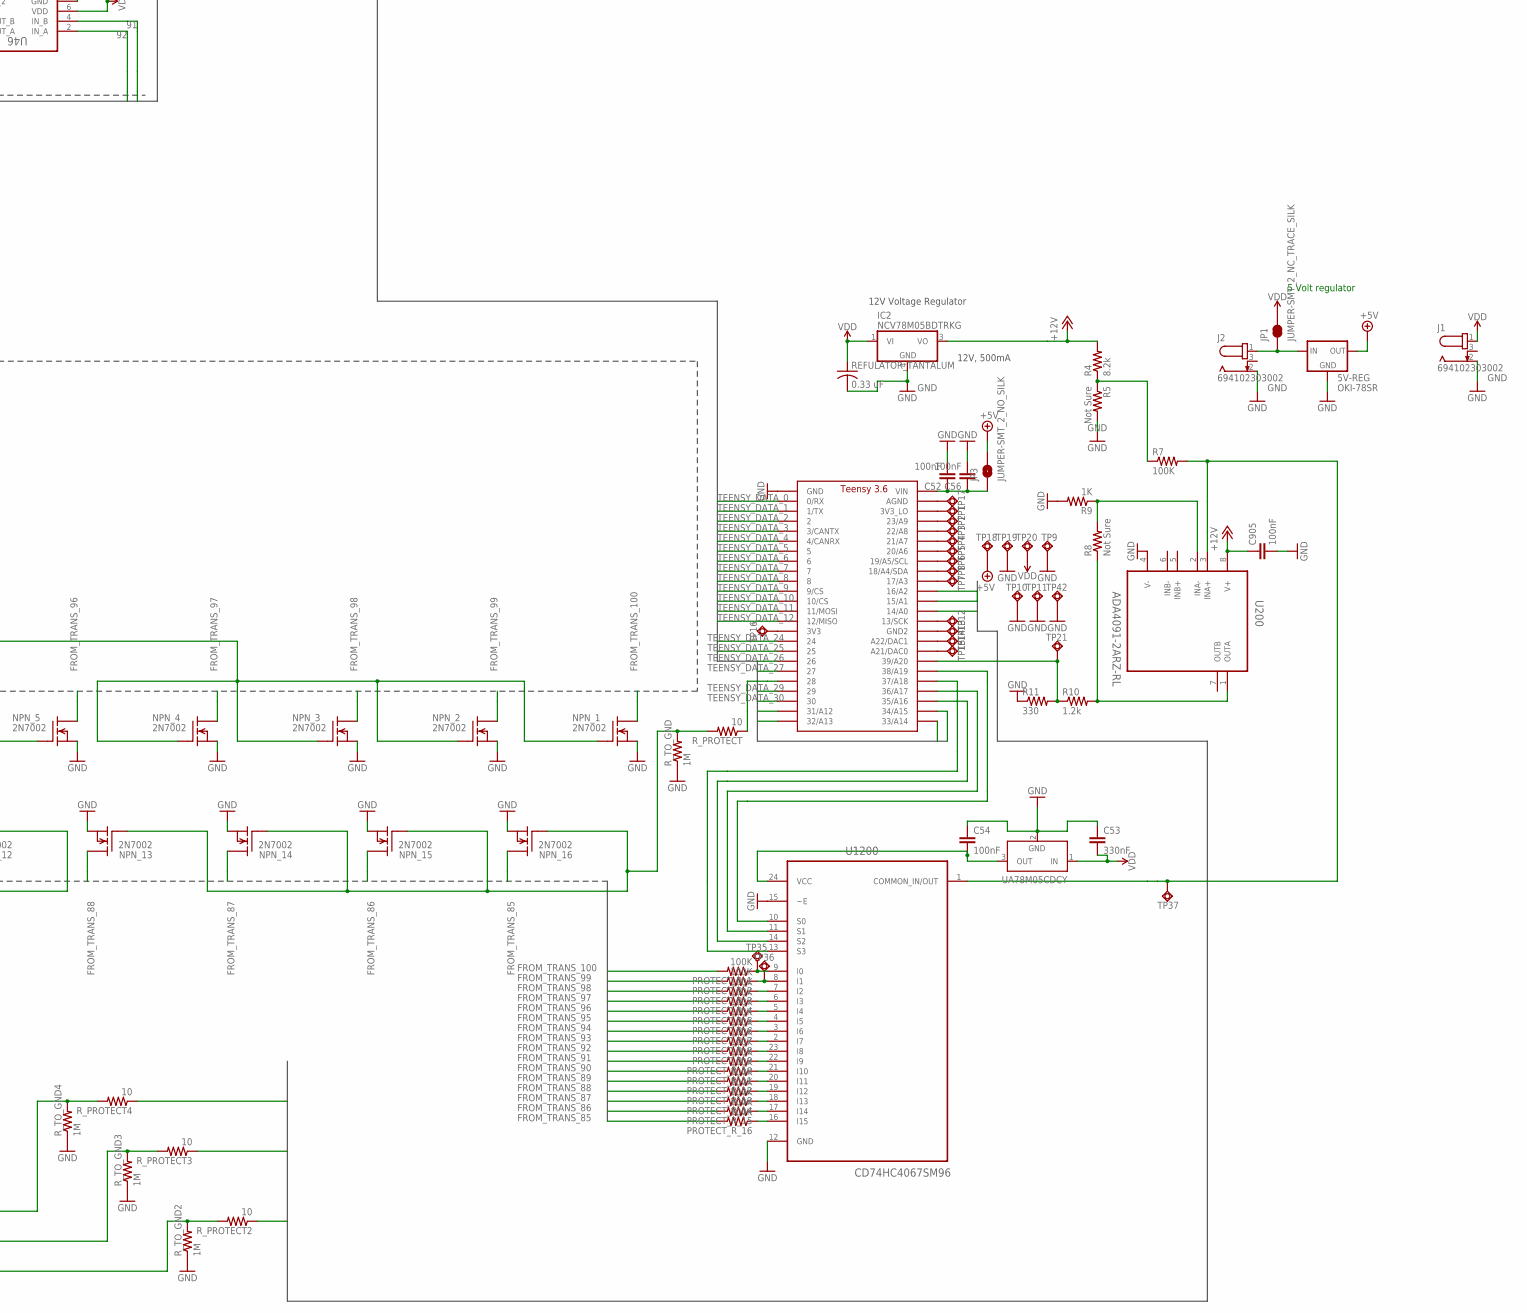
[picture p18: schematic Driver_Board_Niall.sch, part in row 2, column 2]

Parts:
1, 2, 3, 4: PHB_1MM27_2X25_SNS
5V-REG: OKI-78SR; OKI-78SR-HORIZ
C1, C2, C3, C4, C5, C6, C7, C8, C9, C10, C11, C12, C13, C14, C15, C16, C17, C18, C19, C20, C21, C22, C23, C24, C25, C26, C27, C28, C29, C30, C31, C32, C33, C34, C35, C36, C37, C38, C39, C40, C41, C42, C43, C44, C45, C46, C47, C48, C49, C50, C51, C52, C54, C55, C56, C905: 100nF; C0805
C53: 330nF; C0805
DATA_1, DATA_2, DATA_3: MA05-2
DIP2: CORE3S500ESMT; CORE3S500E-SMT
IC2: NCV78M05BDTRKG; DPACK_3
J1, J2: 694102303002; 69410X303002
JP1: JUMPER-SMT_2_NC_TRACE_SILK; SMT-JUMPER_2_NC_TRACE_SILK
JP3: JUMPER-SMT_2_NO_SILK; SMT-JUMPER_2_NO_SILK
NPN_1, NPN_2, NPN_3, NPN_4, NPN_5, NPN_6, NPN_7, NPN_8, NPN_9, NPN_10, NPN_11, NPN_12, NPN_13, NPN_14, NPN_15, NPN_16: 2N7002; SOT23
PROTECT_R_1, PROTECT_R_2, PROTECT_R_3, PROTECT_R_4, PROTECT_R_5, PROTECT_R_6, PROTECT_R_7, PROTECT_R_8, PROTECT_R_9, PROTECT_R_10, PROTECT_R_11, PROTECT_R_12, PROTECT_R_13, PROTECT_R_14, PROTECT_R_15, PROTECT_R_16: 100K; M0805
R4: 8.2k; M0805
R5, R8: Not Sure; M0805
R7: 100K; M0805
R9: 1K; M0805
R10: 1.2k; M0805
R11: 330; M0805
R-TRANS-85, R-TRANS-86, R-TRANS-87, R-TRANS-88, R-TRANS-89, R-TRANS-90, R-TRANS-91, R-TRANS-92, R-TRANS-93, R-TRANS-94, R-TRANS-95, R-TRANS-96, R-TRANS-97, R-TRANS-98, R-TRANS-99, R-TRANS-100: 10k; M0805
REFULATOR_TANTALUM: 0.33 uF; C1206
R_PROTECT, R_PROTECT2, R_PROTECT3, R_PROTECT4: 10; M0805
R_TO_GND, R_TO_GND2, R_TO_GND3, R_TO_GND4: 1M; M0805
TP1, TP2, TP3, TP4, TP5, TP6, TP7, TP8, TP9, TP10, TP11, TP12, TP13, TP14, TP15, TP16, TP17, TP18, TP19, TP20, TP21, TP22, TP23, TP24, TP25, TP26, TP27, TP28, TP29, TP30, TP31, TP32, TP33, TP34, TP35, TP36, TP37, TP38, TP39, TP40, TP41, TP42: TPSQPAD1-13; P1-13
U1, U2, U3, U4, U5, U6, U7, U8, U9, U10, U11, U12, U13, U14, U15, U16, U17, U18, U19, U20, U21, U22, U23, U24, U25, U26, U27, U28, U29, U30, U31, U32, U33, U34, U35, U36, U37, U38, U39, U40, U41, U42, U43, U44, U45, U46, U47, U48, U49, U50: TC4427AEOA; SOIC127P600X175-8N
U200: ADA4091-2ARZ-RL; ADA4091-2ARZ-RL_SOIC127P600X175-8N
U1200: CD74HC4067SM96; SOP65P780X200-24N
U$1: TEENSY_SMD; TEENSY_3.6_SMD
UA78M05CDCY: LT1129CST5; SOT223

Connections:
1: DIP2.75, U1.4 (IN_B)
2: DIP2.77, U1.2 (IN_A)
3: DIP2.8, U2.4 (IN_B)
4: DIP2.39, U2.2 (IN_A)
5: DIP2.74, U3.4 (IN_B)
6: DIP2.63, U3.2 (IN_A)
7: DIP2.41, U4.4 (IN_B)
8: DIP2.45, U4.2 (IN_A)
9: DIP2.55, U5.4 (IN_B)
10: DIP2.47, U5.2 (IN_A)
11: DIP2.48, U6.4 (IN_B)
12: DIP2.50, U6.2 (IN_A)
13: DIP2.40, U7.4 (IN_B)
14: DIP2.36, U7.2 (IN_A)
15: DIP2.60, U8.4 (IN_B)
16: DIP2.62, U8.2 (IN_A)
17: DIP2.29, U9.4 (IN_B)
18: DIP2.23, U9.2 (IN_A)
19: DIP2.64, U10.4 (IN_B)
20: DIP2.69, U10.2 (IN_A)
21: DIP2.19, U11.4 (IN_B)
22: DIP2.25, U11.2 (IN_A)
23: DIP2.192, U12.4 (IN_B)
24: DIP2.196, U12.2 (IN_A)
25: DIP2.102, U13.4 (IN_B)
26: DIP2.109, U13.2 (IN_A)
27: DIP2.31, U14.4 (IN_B)
28: DIP2.34, U14.2 (IN_A)
29: DIP2.133, U15.4 (IN_B)
30: DIP2.138, U15.2 (IN_A)
31: DIP2.42, U16.4 (IN_B)
32: DIP2.49, U16.2 (IN_A)
33: DIP2.145, U17.4 (IN_B)
34: DIP2.151, U17.2 (IN_A)
35: DIP2.61, U18.4 (IN_B)
36: DIP2.65, U18.2 (IN_A)
37: DIP2.189, U19.4 (IN_B)
38: DIP2.186, U19.2 (IN_A)
39: DIP2.76, U20.4 (IN_B)
40: DIP2.82, U20.2 (IN_A)
41: DIP2.16, U21.4 (IN_B)
42: DIP2.9, U21.2 (IN_A)
43: DIP2.202, U22.4 (IN_B)
44: DIP2.199, U22.2 (IN_A)
45: DIP2.126, U23.4 (IN_B)
46: DIP2.128, U23.2 (IN_A)
47: DIP2.164, U24.4 (IN_B)
48: DIP2.167, U24.2 (IN_A)
49: DIP2.147, U25.4 (IN_B)
50: DIP2.140, U25.2 (IN_A)
51: DIP2.135, U26.4 (IN_B)
52: DIP2.129, U26.2 (IN_A)
53: DIP2.116, U27.4 (IN_B)
54: DIP2.123, U27.2 (IN_A)
55: DIP2.127, U28.4 (IN_B)
56: DIP2.120, U28.2 (IN_A)
57: DIP2.205, U29.4 (IN_B)
58: DIP2.12, U29.2 (IN_A)
59: DIP2.90, U30.4 (IN_B)
60: DIP2.97, U30.2 (IN_A)
61: DIP2.99, U31.4 (IN_B)
62: DIP2.94, U31.2 (IN_A)
63: DIP2.113, U32.4 (IN_B)
64: DIP2.107, U32.2 (IN_A)
65: DIP2.93, TP25.TP, U33.4 (IN_B)
66: DIP2.96, TP24.TP, U33.2 (IN_A)
67: DIP2.98, U34.4 (IN_B)
68: DIP2.100, U34.2 (IN_A)
69: DIP2.106, TP30.TP, U35.4 (IN_B)
70: DIP2.108, TP29.TP, U35.2 (IN_A)
71: DIP2.112, U36.4 (IN_B)
72: DIP2.115, U36.2 (IN_A)
73: DIP2.119, U37.4 (IN_B)
74: DIP2.122, U37.2 (IN_A)
75: DIP2.178, U38.4 (IN_B)
76: DIP2.180, U38.2 (IN_A)
77: DIP2.162, U39.4 (IN_B)
78: DIP2.165, U39.2 (IN_A)
79: DIP2.185, U40.4 (IN_B)
80: DIP2.187, U40.2 (IN_A)
81: DIP2.153, U41.4 (IN_B)
82: DIP2.160, U41.2 (IN_A)
83: DIP2.190, U42.4 (IN_B)
84: DIP2.193, U42.2 (IN_A)
85: DIP2.172, U43.4 (IN_B)
86: DIP2.168, U43.2 (IN_A)
87: DIP2.177, U44.4 (IN_B)
88: DIP2.171, U44.2 (IN_A)
89: DIP2.163, U45.4 (IN_B)
90: DIP2.161, U45.2 (IN_A)
91: DIP2.179, U46.4 (IN_B)
92: DIP2.181, U46.2 (IN_A)
93: DIP2.146, U47.4 (IN_B)
94: DIP2.144, U47.2 (IN_A)
95: DIP2.152, U48.4 (IN_B)
96: DIP2.150, U48.2 (IN_A)
97: DIP2.134, U49.4 (IN_B)
98: DIP2.132, U49.2 (IN_A)
99: DIP2.139, U50.4 (IN_B)
100: DIP2.137, U50.2 (IN_A)
+5V: 5V-REG.OUT, C51.1, C55.1, DATA_1.10, DATA_2.10, DATA_3.10, DIP2.5V@2 (5V), JP3.2, TP18.TP
+12V: C905.1, IC2.3 (VO), R4.2, U200.8 (V+)
FET_2: R_PROTECT2.1, U$1.16/A4 (16/A2)
FET_3: R_PROTECT3.1, U$1.15/A4 (15/A1)
FET_4: R_PROTECT4.1, U$1.14/A3 (14/A0)
FPGA_1: DATA_1.1, DIP2.35
FPGA_2: DATA_1.3, DIP2.33
FPGA_3: DATA_1.5, DIP2.30
FPGA_4: DATA_1.7, DIP2.28
FPGA_10: DATA_2.7, DIP2.197
FPGA_11: DATA_2.5, DIP2.200
FPGA_12: DATA_2.3, DIP2.203
FPGA_13: DATA_2.1, DIP2.2
FROM_TRANS_85: 1.50, NPN_16.3 (D), PROTECT_R_16.2, R-TRANS-85.1
FROM_TRANS_86: 1.48, NPN_15.3 (D), PROTECT_R_15.2, R-TRANS-86.1
FROM_TRANS_87: 1.46, NPN_14.3 (D), PROTECT_R_14.2, R-TRANS-87.1
FROM_TRANS_88: 1.44, NPN_13.3 (D), PROTECT_R_13.2, R-TRANS-88.1
FROM_TRANS_89: 1.42, NPN_12.3 (D), PROTECT_R_12.2, R-TRANS-89.1
FROM_TRANS_90: 1.40, NPN_11.3 (D), PROTECT_R_11.2, R-TRANS-90.1
FROM_TRANS_91: 1.38, NPN_10.3 (D), PROTECT_R_10.2, R-TRANS-91.1
FROM_TRANS_92: 1.36, NPN_9.3 (D), PROTECT_R_9.2, R-TRANS-92.1
FROM_TRANS_93: 1.16, NPN_8.3 (D), PROTECT_R_8.2, R-TRANS-93.1
FROM_TRANS_94: 1.14, NPN_7.3 (D), PROTECT_R_7.2, R-TRANS-94.1
FROM_TRANS_95: 1.12, NPN_6.3 (D), PROTECT_R_6.2, R-TRANS-95.1
FROM_TRANS_96: 1.10, NPN_5.3 (D), PROTECT_R_5.2, R-TRANS-96.1
FROM_TRANS_97: 1.8, NPN_4.3 (D), PROTECT_R_4.2, R-TRANS-97.1
FROM_TRANS_98: 1.6, NPN_3.3 (D), PROTECT_R_3.2, R-TRANS-98.1
FROM_TRANS_99: 1.4, NPN_2.3 (D), PROTECT_R_2.2, R-TRANS-99.1
FROM_TRANS_100: 1.2, NPN_1.3 (D), PROTECT_R_1.2, R-TRANS-100.1
GND: 1.18, 1.20, 1.22, 1.24, 1.26, 1.28, 1.30, 1.32, 1.34, 2.2, 2.3, 2.6, 2.7, 2.10, 2.11, 2.14, 2.15, 2.18, 2.19, 2.22, 2.23, 2.26, 2.27, 2.30, 2.31, 2.34, 2.35, 2.38, 2.39, 2.42, 2.43, 2.46, 2.47, 2.50, 3.2, 3.3, 3.6, 3.7, 3.10, 3.11, 3.14, 3.15, 3.18, 3.19, 3.22, 3.23, 3.26, 3.27, 3.30, 3.31, 3.34, 3.35, 3.38, 3.39, 3.42, 3.43, 3.46, 3.47, 3.50, 4.2, 4.3, 4.6, 4.7, 4.10, 4.11, 4.14, 4.15, 4.18, 4.19, 4.22, 4.23, 4.26, 4.27, 4.30, 4.31, 4.34, 4.35, 4.38, 4.39, 4.42, 4.43, 4.46, 4.47, 4.50, 5V-REG.GND, C1.1, C2.1, C3.1, C4.1, C5.1, C6.1, C7.1, C8.1, C9.1, C10.1, C11.1, C12.1, C13.1, C14.1, C15.1, C16.1, C17.1, C18.1, C19.1, C20.1, C21.1, C22.1, C23.1, C24.1, C25.1, C26.1, C27.1, C28.1, C29.1, C30.1, C31.1, C32.1, C33.1, C34.1, C35.1, C36.1, C37.1, C38.1, C39.1, C40.1, C41.1, C42.1, C43.1, C44.1, C45.1, C46.1, C47.1, C48.1, C49.1, C50.1, C51.2, C52.2, C53.1, C54.1, C55.2, C56.2, C905.2, DATA_1.9, DATA_2.9, DATA_3.9, DIP2.GND@4 (GND), IC2.4 (GND), J1.2, J2.2, NPN_1.2 (S), NPN_2.2 (S), NPN_3.2 (S), NPN_4.2 (S), NPN_5.2 (S), NPN_6.2 (S), NPN_7.2 (S), NPN_8.2 (S), NPN_9.2 (S), NPN_10.2 (S), NPN_11.2 (S), NPN_12.2 (S), NPN_13.2 (S), NPN_14.2 (S), NPN_15.2 (S), NPN_16.2 (S), R5.2, R9.2, R11.1, REFULATOR_TANTALUM.2, R_TO_GND.1, R_TO_GND2.1, R_TO_GND3.1, R_TO_GND4.1, TP9.TP, TP10.TP, TP11.TP, TP19.TP, TP26.TP, TP31.TP, TP42.TP, U1.3 (GND), U2.3 (GND), U3.3 (GND), U4.3 (GND), U5.3 (GND), U6.3 (GND), U7.3 (GND), U8.3 (GND), U9.3 (GND), U10.3 (GND), U11.3 (GND), U12.3 (GND), U13.3 (GND), U14.3 (GND), U15.3 (GND), U16.3 (GND), U17.3 (GND), U18.3 (GND), U19.3 (GND), U20.3 (GND), U21.3 (GND), U22.3 (GND), U23.3 (GND), U24.3 (GND), U25.3 (GND), U26.3 (GND), U27.3 (GND), U28.3 (GND), U29.3 (GND), U30.3 (GND), U31.3 (GND), U32.3 (GND), U33.3 (GND), U34.3 (GND), U35.3 (GND), U36.3 (GND), U37.3 (GND), U38.3 (GND), U39.3 (GND), U40.3 (GND), U41.3 (GND), U42.3 (GND), U43.3 (GND), U44.3 (GND), U45.3 (GND), U46.3 (GND), U47.3 (GND), U48.3 (GND), U49.3 (GND), U50.3 (GND), U200.4 (V-), U1200.12 (GND), U1200.15 (~E), U$1.GND6 (GND), UA78M05CDCY.2 (GND), UA78M05CDCY.4 (GND)
unnamed: PROTECT_R_1.1, TP35.TP, U1200.9 (I0)
unnamed: R4.1, R5.1, R7.1
unnamed: PROTECT_R_2.1, TP36.TP, U1200.8 (I1)
unnamed: R10.1, R11.2, TP21.TP, U$1.39/A3 (39/A20)
unnamed: U1200.10 (S0), U$1.38/A3 (38/A19)
unnamed: R8.1, R10.2, U200.1 (OUTA)
unnamed: R_PROTECT.1, U$1.28
unnamed: TP1.TP, U$1.3V3_LO3 (3V3_LO)
unnamed: U1200.13 (S3), U$1.37/A3 (37/A18)
unnamed: U1200.14 (S2), U$1.35/A3 (35/A16)
unnamed: U1200.11 (S1), U$1.36/A3 (36/A17)
unnamed: TP2.TP, U$1.23/A3 (23/A9)
unnamed: R8.2, R9.1, U200.2 (INA-)
unnamed: TP3.TP, U$1.22/A3 (22/A8)
unnamed: TP4.TP, U$1.21/A3 (21/A7)
unnamed: TP5.TP, U$1.20/A3 (20/A6)
unnamed: TP6.TP, U$1.19/A5/SCL3 (19/A5/SCL)
unnamed: TP7.TP, U$1.17/A4 (17/A3)
unnamed: TP8.TP, U$1.18/A4/SDA3 (18/A4/SDA)
unnamed: NPN_1.1 (G), NPN_2.1 (G), NPN_3.1 (G), NPN_4.1 (G), R_PROTECT3.2, R_TO_GND3.2
unnamed: C54.2, U1200.24 (VCC), UA78M05CDCY.3 (OUT)
unnamed: 5V-REG.IN, J2.1, JP1.1
unnamed: C52.1, C56.1, JP3.1, U$1.VIN3 (VIN)
unnamed: NPN_5.1 (G), NPN_6.1 (G), NPN_7.1 (G), NPN_8.1 (G), R_PROTECT4.2, R_TO_GND4.2
unnamed: TP12.TP, U$1.13/SCK3 (13/SCK)
unnamed: TP13.TP, U$1.GND7 (GND2)
unnamed: TP14.TP, U$1.A22/DAC1
unnamed: TP15.TP, U$1.A21/DAC0
unnamed: TP16.TP, U$1.3V4 (3V3)
unnamed: R7.2, TP37.TP, U200.3 (INA+), U1200.1 (COMMON_IN/OUT)
unnamed: TP17.TP, U$1.AGND3 (AGND)
unnamed: PROTECT_R_3.1, U1200.7 (I2)
unnamed: NPN_13.1 (G), NPN_14.1 (G), NPN_15.1 (G), NPN_16.1 (G), R_PROTECT.2, R_TO_GND.2
unnamed: NPN_9.1 (G), NPN_10.1 (G), NPN_11.1 (G), NPN_12.1 (G), R_PROTECT2.2, R_TO_GND2.2
unnamed: PROTECT_R_4.1, U1200.6 (I3)
unnamed: PROTECT_R_5.1, U1200.5 (I4)
unnamed: PROTECT_R_6.1, U1200.4 (I5)
unnamed: PROTECT_R_7.1, U1200.3 (I6)
unnamed: PROTECT_R_8.1, U1200.2 (I7)
unnamed: PROTECT_R_9.1, U1200.23 (I8)
unnamed: PROTECT_R_10.1, U1200.22 (I9)
unnamed: PROTECT_R_11.1, U1200.21 (I10)
unnamed: PROTECT_R_12.1, U1200.20 (I11)
unnamed: PROTECT_R_13.1, U1200.19 (I12)
unnamed: PROTECT_R_14.1, U1200.18 (I13)
unnamed: PROTECT_R_15.1, U1200.17 (I14)
unnamed: PROTECT_R_16.1, U1200.16 (I15)
TEENSY_DATA_0: DATA_1.2, U$1.0/RX3 (0/RX)
TEENSY_DATA_1: DATA_1.4, U$1.1/TX3 (1/TX)
TEENSY_DATA_2: DATA_1.6, U$1.2
TEENSY_DATA_3: DATA_1.8, U$1.3/CANTX3 (3/CANTX)
TEENSY_DATA_4: DIP2.24, TP34.TP, U$1.4/CANRX3 (4/CANRX)
TEENSY_DATA_5: DIP2.11, TP41.TP, U$1.5
TEENSY_DATA_6: DIP2.15, TP40.TP, U$1.6
TEENSY_DATA_7: DIP2.18, TP39.TP, U$1.7
TEENSY_DATA_8: DIP2.22, TP38.TP, U$1.8
TEENSY_DATA_9: DATA_2.2, U$1.9/CS3 (9/CS)
TEENSY_DATA_10: DATA_2.4, U$1.10/CS3 (10/CS)
TEENSY_DATA_11: DATA_2.6, U$1.11/MOSI3 (11/MOSI)
TEENSY_DATA_12: DATA_2.8, U$1.12/MISO3 (12/MISO)
TEENSY_DATA_24: DATA_3.2, U$1.24
TEENSY_DATA_25: DATA_3.1, U$1.25
TEENSY_DATA_26: DATA_3.3, U$1.26
TEENSY_DATA_27: DATA_3.4, U$1.27
TEENSY_DATA_29: DATA_3.6, U$1.29
TEENSY_DATA_30: DATA_3.5, U$1.30
TEENSY_DATA_31: DATA_3.7, U$1.31/A3 (31/A12)
TEENSY_DATA_32: DATA_3.8, U$1.32/A3 (32/A13)
TEENSY_DATA_33: U$1.33/A3 (33/A14)
TEENSY_DATA_34: U$1.34/A3 (34/A15)
TO_TRAN_1: 4.9, U1.5 (*OUT_B)
TO_TRAN_2: 4.5, U1.7 (*OUT_A)
TO_TRAN_3: 4.49, U2.5 (*OUT_B)
TO_TRAN_4: 4.45, U2.7 (*OUT_A)
TO_TRAN_5: 4.4, U3.5 (*OUT_B)
TO_TRAN_6: 4.8, U3.7 (*OUT_A)
TO_TRAN_7: 4.41, U4.5 (*OUT_B)
TO_TRAN_8: 4.37, U4.7 (*OUT_A)
TO_TRAN_9: 4.12, U5.5 (*OUT_B)
TO_TRAN_10: 4.16, U5.7 (*OUT_A)
TO_TRAN_11: 4.33, U6.5 (*OUT_B)
TO_TRAN_12: 4.29, U6.7 (*OUT_A)
TO_TRAN_13: 4.20, U7.5 (*OUT_B)
TO_TRAN_14: 4.24, U7.7 (*OUT_A)
TO_TRAN_15: 4.25, U8.5 (*OUT_B)
TO_TRAN_16: 4.21, U8.7 (*OUT_A)
TO_TRAN_17: 4.28, U9.5 (*OUT_B)
TO_TRAN_18: 4.32, U9.7 (*OUT_A)
TO_TRAN_19: 4.17, U10.5 (*OUT_B)
TO_TRAN_20: 4.13, U10.7 (*OUT_A)
TO_TRAN_21: 3.33, U11.5 (*OUT_B)
TO_TRAN_22: 3.29, U11.7 (*OUT_A)
TO_TRAN_23: 3.49, U12.5 (*OUT_B)
TO_TRAN_24: 3.45, U12.7 (*OUT_A)
TO_TRAN_25: 3.12, U13.5 (*OUT_B)
TO_TRAN_26: 3.16, U13.7 (*OUT_A)
TO_TRAN_27: 3.25, U14.5 (*OUT_B)
TO_TRAN_28: 3.21, U14.7 (*OUT_A)
TO_TRAN_29: 3.28, U15.5 (*OUT_B)
TO_TRAN_30: 3.32, U15.7 (*OUT_A)
TO_TRAN_31: 3.17, U16.5 (*OUT_B)
TO_TRAN_32: 3.13, U16.7 (*OUT_A)
TO_TRAN_33: 3.36, U17.5 (*OUT_B)
TO_TRAN_34: 3.40, U17.7 (*OUT_A)
TO_TRAN_35: 3.9, U18.5 (*OUT_B)
TO_TRAN_36: 3.5, U18.7 (*OUT_A)
TO_TRAN_37: 3.44, U19.5 (*OUT_B)
TO_TRAN_38: 3.48, U19.7 (*OUT_A)
TO_TRAN_39: 3.1, U20.5 (*OUT_B)
TO_TRAN_40: 4.1, U20.7 (*OUT_A)
TO_TRAN_41: 4.36, U21.5 (*OUT_B)
TO_TRAN_42: 4.40, U21.7 (*OUT_A)
TO_TRAN_43: 4.44, U22.5 (*OUT_B)
TO_TRAN_44: 4.48, U22.7 (*OUT_A)
TO_TRAN_45: 2.44, U23.5 (*OUT_B)
TO_TRAN_46: 2.48, U23.7 (*OUT_A)
TO_TRAN_47: 2.45, U24.5 (*OUT_B)
TO_TRAN_48: 2.41, U24.7 (*OUT_A)
TO_TRAN_49: 2.37, U25.5 (*OUT_B)
TO_TRAN_50: 2.33, U25.7 (*OUT_A)
TO_TRAN_51: 2.29, U26.5 (*OUT_B)
TO_TRAN_52: 2.25, U26.7 (*OUT_A)
TO_TRAN_53: 3.20, U27.5 (*OUT_B)
TO_TRAN_54: 3.24, U27.7 (*OUT_A)
TO_TRAN_55: 2.21, U28.5 (*OUT_B)
TO_TRAN_56: 2.17, U28.7 (*OUT_A)
TO_TRAN_57: 3.41, U29.5 (*OUT_B)
TO_TRAN_58: 3.37, U29.7 (*OUT_A)
TO_TRAN_59: 3.4, U30.5 (*OUT_B)
TO_TRAN_60: 3.8, U30.7 (*OUT_A)
TO_TRAN_61: 2.5, U31.5 (*OUT_B)
TO_TRAN_62: 2.1, U31.7 (*OUT_A)
TO_TRAN_63: 2.13, U32.5 (*OUT_B)
TO_TRAN_64: 2.9, U32.7 (*OUT_A)
TO_TRAN_65: 2.4, TP23.TP, U33.5 (*OUT_B)
TO_TRAN_66: 2.8, TP22.TP, U33.7 (*OUT_A)
TO_TRAN_67: 2.12, U34.5 (*OUT_B)
TO_TRAN_68: 2.16, U34.7 (*OUT_A)
TO_TRAN_69: 2.20, TP27.TP, U35.5 (*OUT_B)
TO_TRAN_70: 2.24, TP28.TP, U35.7 (*OUT_A)
TO_TRAN_71: 2.28, U36.5 (*OUT_B)
TO_TRAN_72: 2.32, U36.7 (*OUT_A)
TO_TRAN_73: 2.36, U37.5 (*OUT_B)
TO_TRAN_74: 2.40, U37.7 (*OUT_A)
TO_TRAN_75: 2.49, U38.5 (*OUT_B)
TO_TRAN_76: 1.33, U38.7 (*OUT_A)
TO_TRAN_77: 1.31, U39.5 (*OUT_B)
TO_TRAN_78: 1.29, U39.7 (*OUT_A)
TO_TRAN_79: 1.27, U40.5 (*OUT_B)
TO_TRAN_80: 1.25, U40.7 (*OUT_A)
TO_TRAN_81: 1.23, U41.5 (*OUT_B)
TO_TRAN_82: 1.21, U41.7 (*OUT_A)
TO_TRAN_83: 1.19, U42.5 (*OUT_B)
TO_TRAN_84: 1.17, U42.7 (*OUT_A)
TO_TRAN_85: 1.49, R-TRANS-85.2, U43.5 (*OUT_B)
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

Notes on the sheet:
12V Voltage Regulator
12V, 500mA
5 Volt regulator
NOT IN ORDER!

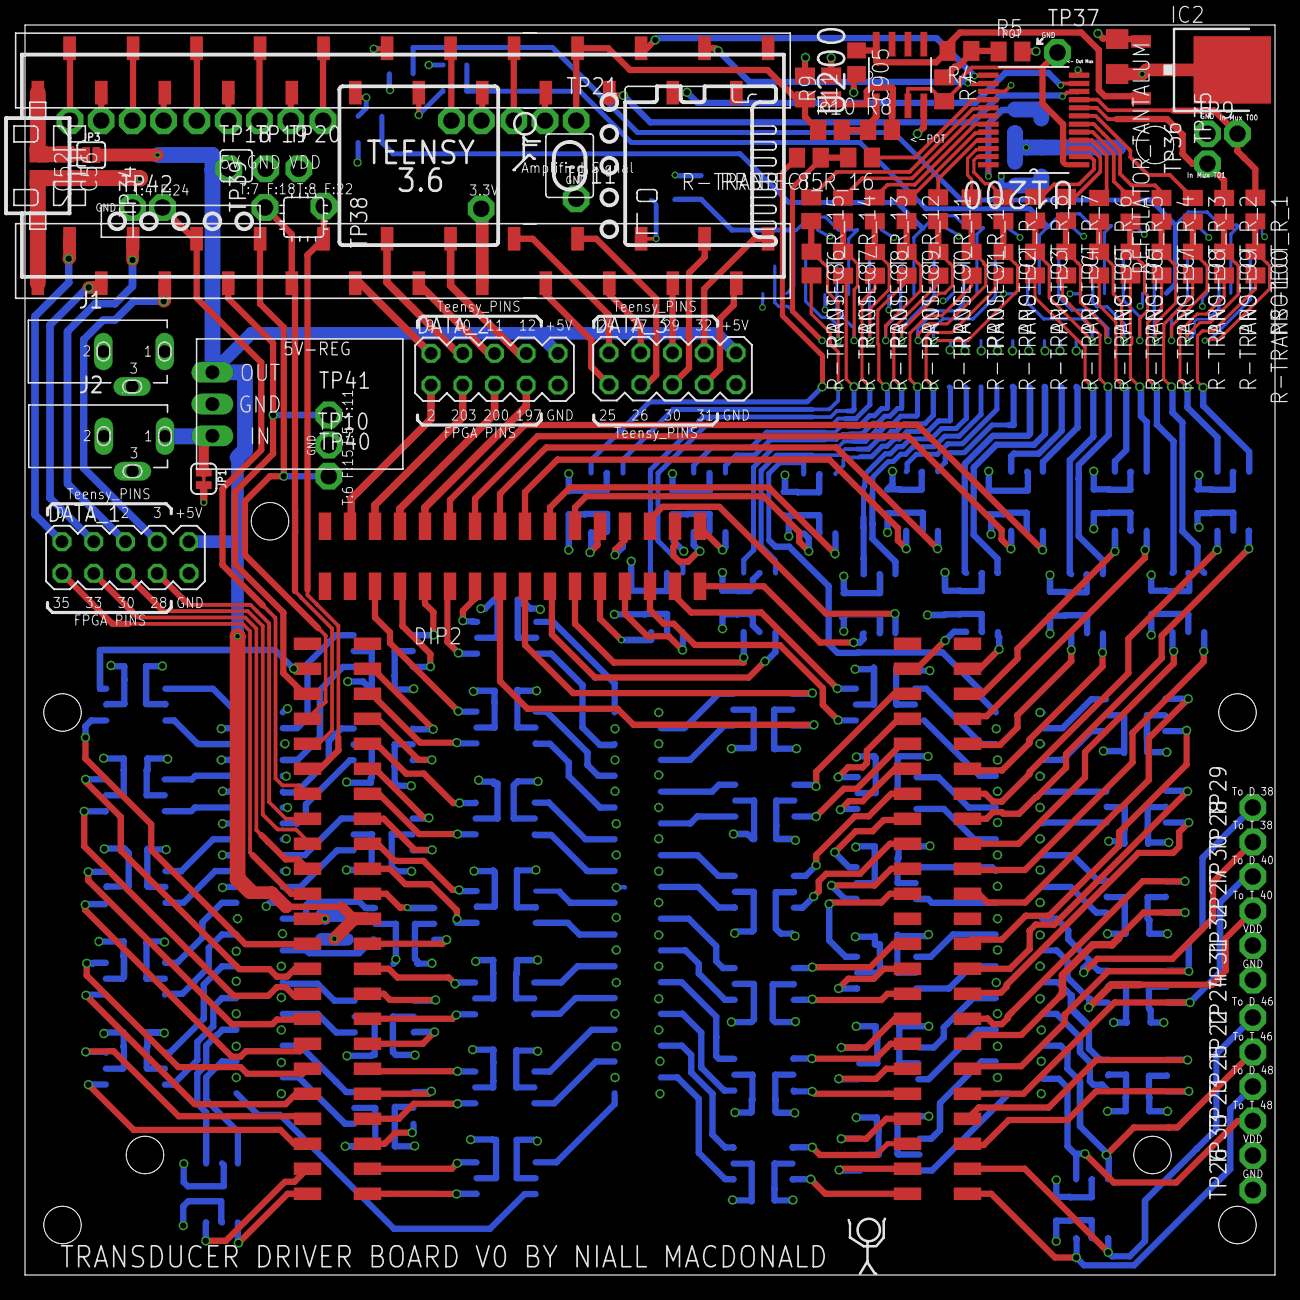
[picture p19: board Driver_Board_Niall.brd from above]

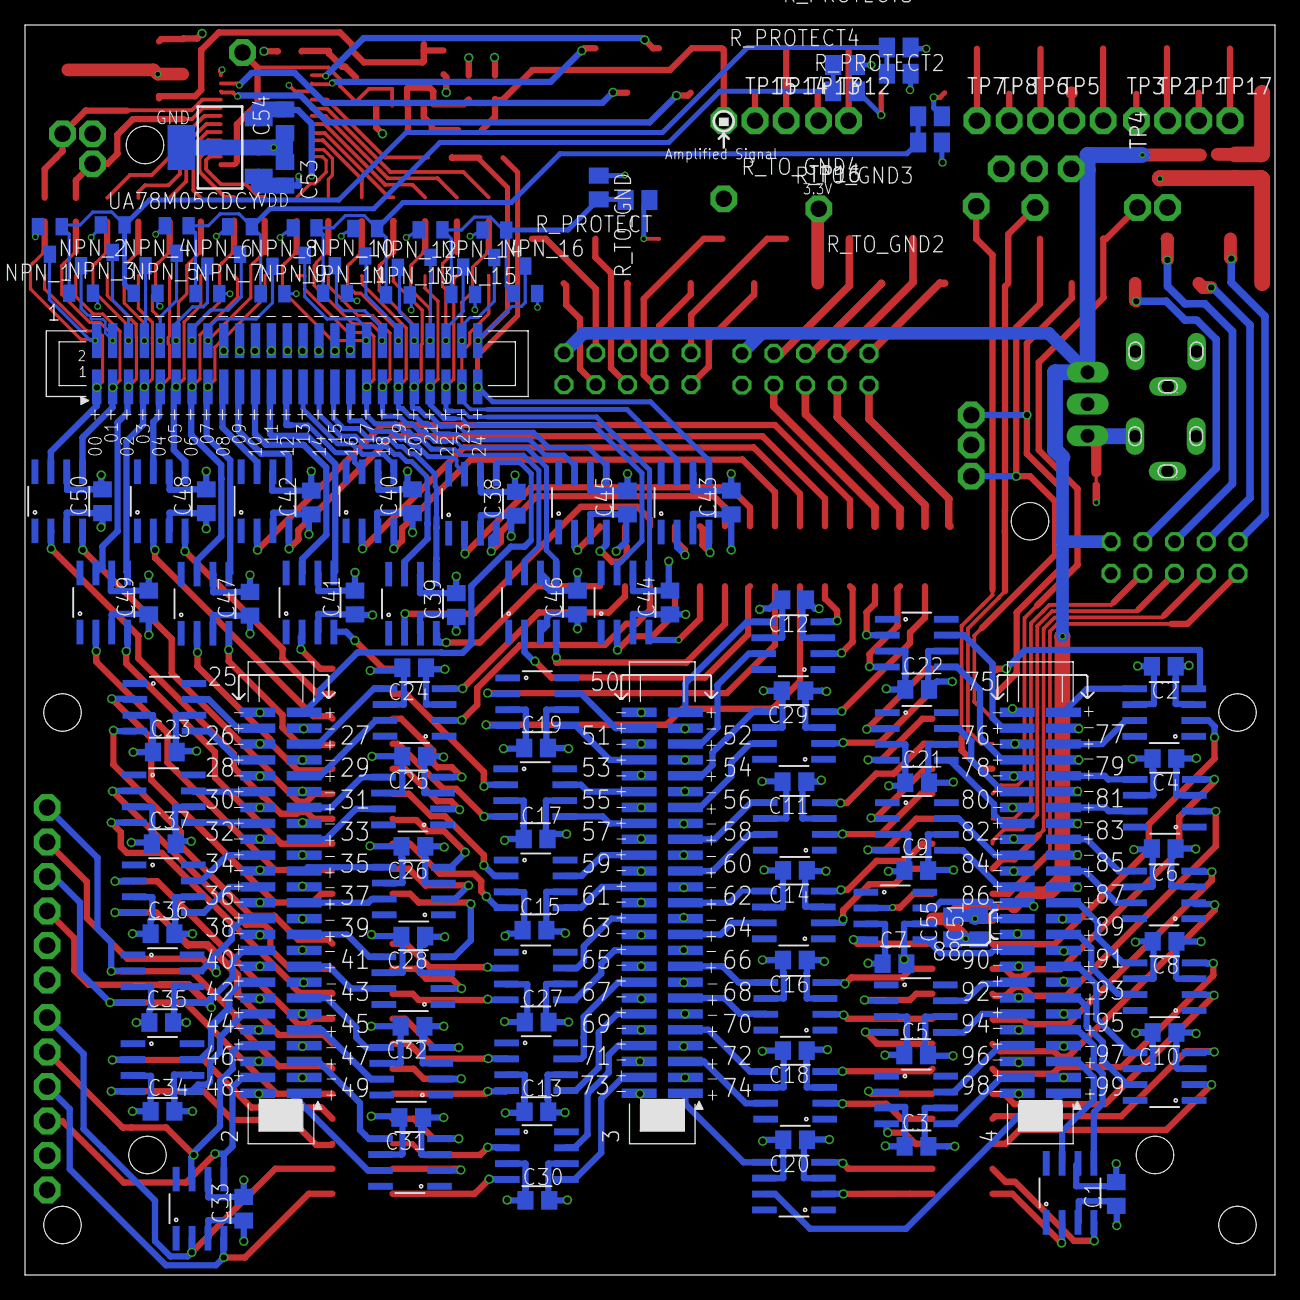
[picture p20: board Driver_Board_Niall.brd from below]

Board: 4 copper layers, 100.0 x 100.0 mm, 231 parts (147 on the bottom side), 299 nets.

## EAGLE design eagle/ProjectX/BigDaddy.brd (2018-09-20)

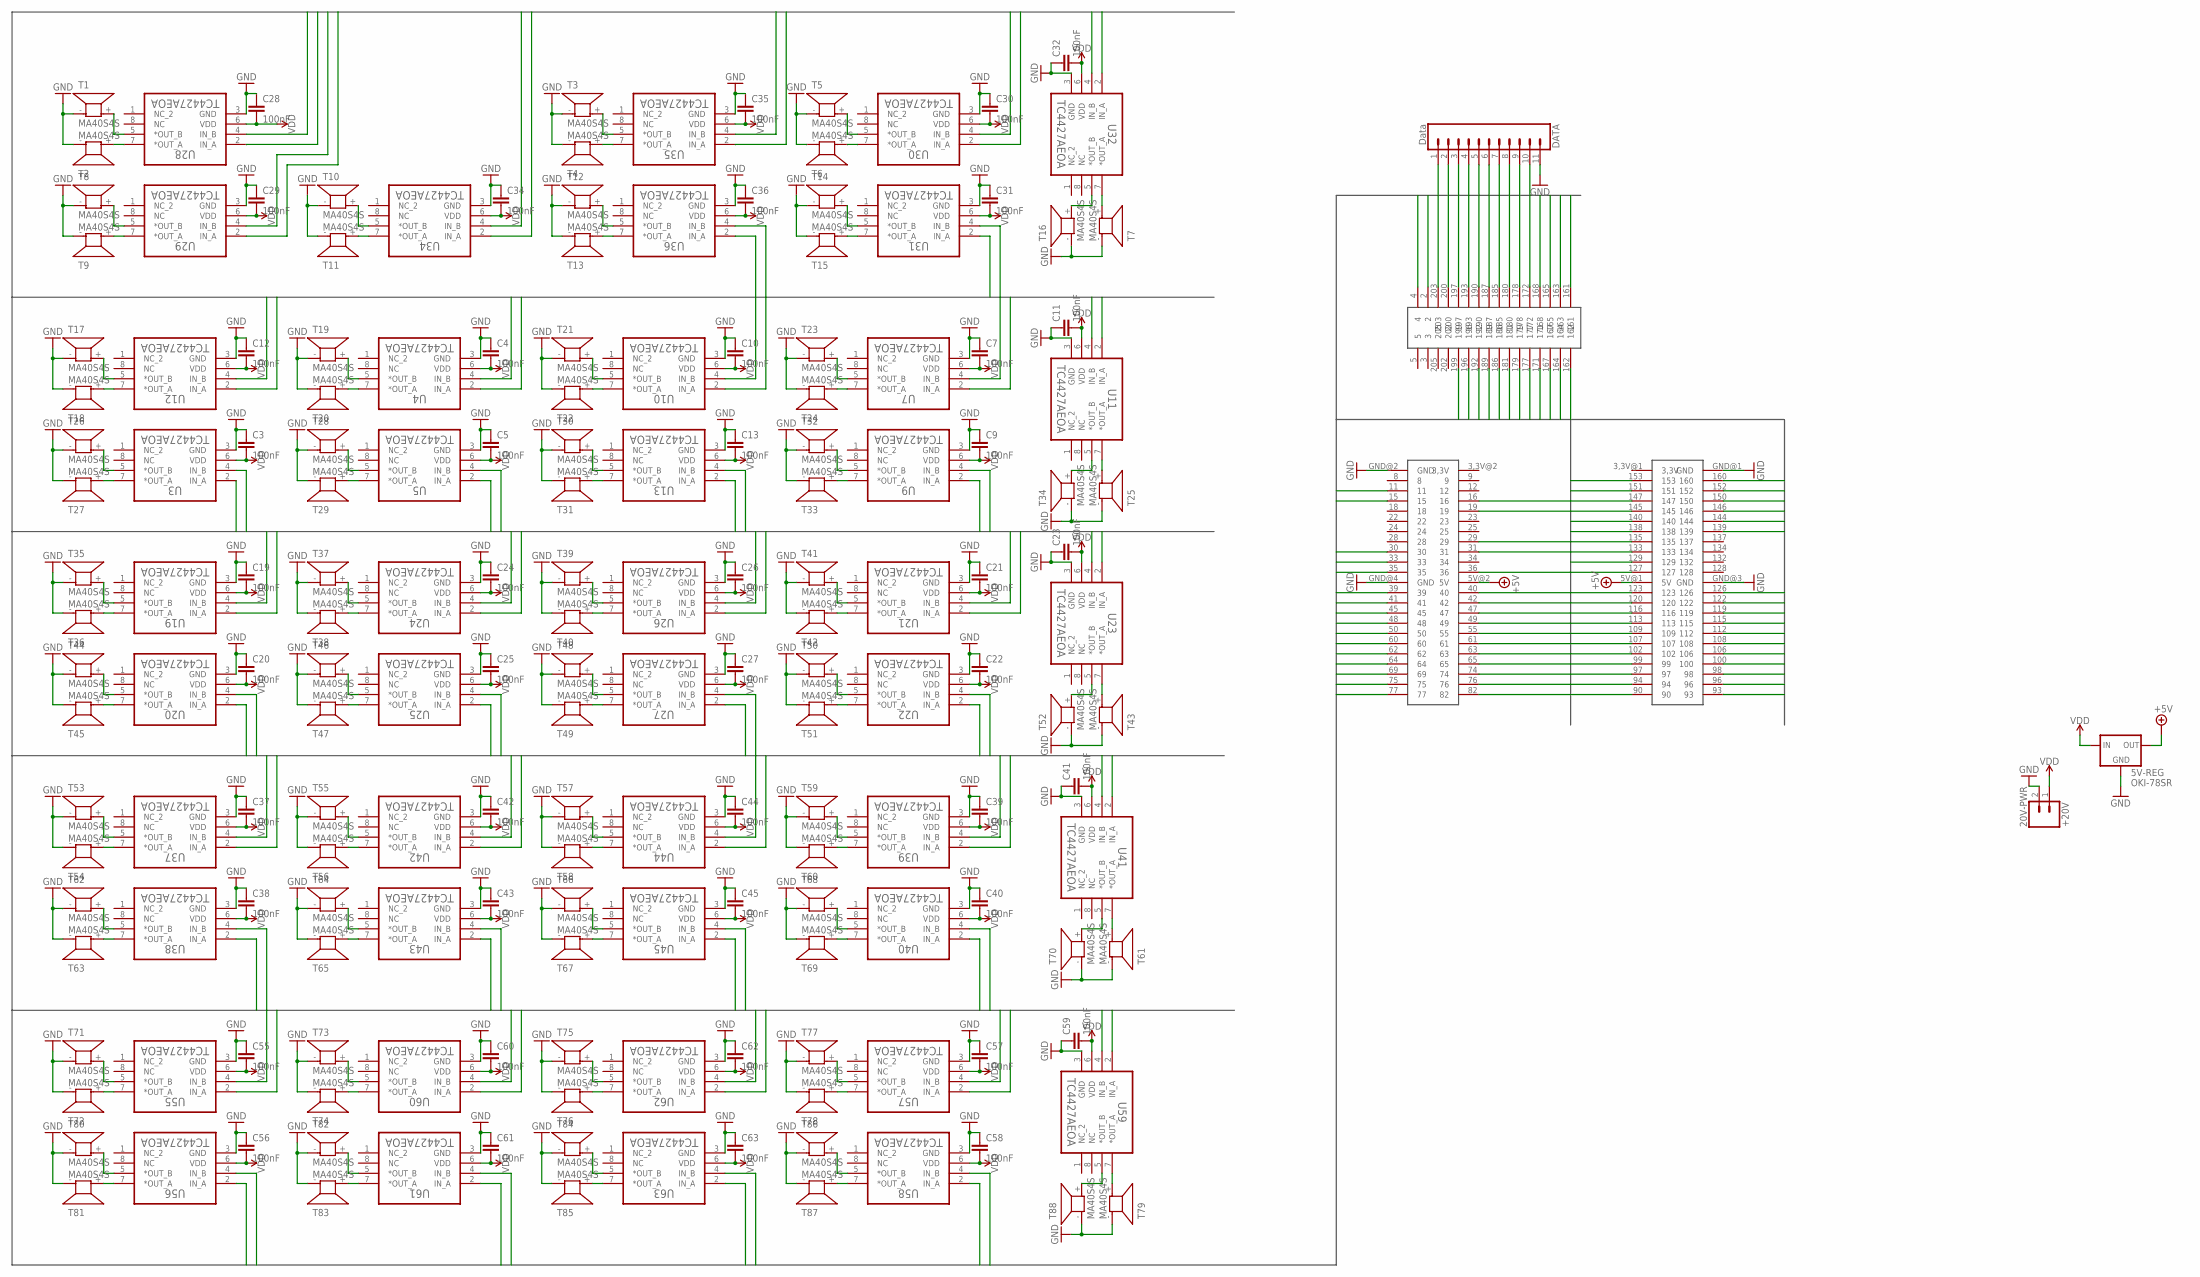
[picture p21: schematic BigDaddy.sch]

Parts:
5V-REG: OKI-78SR; OKI-78SR-HORIZ
20V-PWR: +20V; 1X02_LOCK_LONGPADS
C3, C4, C5, C7, C9, C10, C11, C12, C13, C19, C20, C21, C22, C23, C24, C25, C26, C27, C28, C29, C30, C31, C32, C34, C35, C36, C37, C38, C39, C40, C41, C42, C43, C44, C45, C55, C56, C57, C58, C59, C60, C61, C62, C63: 100nF; C0805
DATA: Data; 1X11
DIP1: CORE3S500ESMT; CORE3S500E-SMT
T1, T2, T3, T4, T5, T6, T7, T8, T9, T10, T11, T12, T13, T14, T15, T16, T17, T18, T19, T20, T21, T22, T23, T24, T25, T26, T27, T28, T29, T30, T31, T32, T33, T34, T35, T36, T37, T38, T39, T40, T41, T42, T43, T44, T45, T46, T47, T48, T49, T50, T51, T52, T53, T54, T55, T56, T57, T58, T59, T60, T61, T62, T63, T64, T65, T66, T67, T68, T69, T70, T71, T72, T73, T74, T75, T76, T77, T78, T79, T80, T81, T82, T83, T84, T85, T86, T87, T88: MA40S4S; MA40
U3, U4, U5, U7, U9, U10, U11, U12, U13, U19, U20, U21, U22, U23, U24, U25, U26, U27, U28, U29, U30, U31, U32, U34, U35, U36, U37, U38, U39, U40, U41, U42, U43, U44, U45, U55, U56, U57, U58, U59, U60, U61, U62, U63: TC4427AEOA; SOIC127P600X175-8N

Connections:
1: DIP1.2, U28.4 (IN_B)
2: DIP1.4, U28.2 (IN_A)
3: DIP1.165, U35.4 (IN_B)
4: DIP1.168, U35.2 (IN_A)
5: DIP1.163, U30.4 (IN_B)
6: DIP1.161, U30.2 (IN_A)
7: DIP1.162, U32.2 (IN_A)
8: DIP1.196, U29.4 (IN_B)
9: DIP1.199, U29.2 (IN_A)
10: DIP1.192, U34.4 (IN_B)
11: DIP1.189, U34.2 (IN_A)
12: DIP1.177, U36.4 (IN_B)
13: DIP1.179, U36.2 (IN_A)
14: DIP1.171, U31.4 (IN_B)
15: DIP1.167, U31.2 (IN_A)
16: DIP1.164, U32.4 (IN_B)
17: DIP1.11, U12.4 (IN_B)
18: DIP1.15, U12.2 (IN_A)
19: DIP1.19, U4.4 (IN_B)
20: DIP1.16, U4.2 (IN_A)
21: DIP1.186, U10.4 (IN_B)
22: DIP1.181, U10.2 (IN_A)
23: DIP1.152, U7.4 (IN_B)
24: DIP1.160, U7.2 (IN_A)
25: DIP1.150, U11.2 (IN_A)
26: DIP1.30, U3.4 (IN_B)
27: DIP1.33, U3.2 (IN_A)
28: DIP1.31, U5.4 (IN_B)
29: DIP1.29, U5.2 (IN_A)
30: DIP1.153, U13.4 (IN_B)
31: DIP1.151, U13.2 (IN_A)
32: DIP1.139, U9.4 (IN_B)
33: DIP1.144, U9.2 (IN_A)
34: DIP1.146, U11.4 (IN_B)
35: DIP1.35, U19.4 (IN_B)
36: DIP1.39, U19.2 (IN_A)
37: DIP1.40, U24.4 (IN_B)
38: DIP1.36, U24.2 (IN_A)
39: DIP1.147, U26.4 (IN_B)
40: DIP1.145, U26.2 (IN_A)
41: DIP1.122, U21.4 (IN_B)
42: DIP1.126, U21.2 (IN_A)
43: DIP1.119, U23.2 (IN_A)
44: DIP1.41, U20.4 (IN_B)
45: DIP1.45, U20.2 (IN_A)
46: DIP1.47, U25.4 (IN_B)
47: DIP1.42, U25.2 (IN_A)
48: DIP1.140, U27.4 (IN_B)
49: DIP1.138, U27.2 (IN_A)
50: DIP1.108, U22.4 (IN_B)
51: DIP1.112, U22.2 (IN_A)
52: DIP1.115, U23.4 (IN_B)
53: DIP1.48, U37.4 (IN_B)
54: DIP1.50, U37.2 (IN_A)
55: DIP1.55, U42.4 (IN_B)
56: DIP1.49, U42.2 (IN_A)
57: DIP1.135, U44.4 (IN_B)
58: DIP1.133, U44.2 (IN_A)
59: DIP1.100, U39.4 (IN_B)
60: DIP1.106, U39.2 (IN_A)
61: DIP1.98, U41.2 (IN_A)
62: DIP1.77, U38.4 (IN_B)
63: DIP1.75, U38.2 (IN_A)
64: DIP1.63, U43.4 (IN_B)
65: DIP1.61, U43.2 (IN_A)
66: DIP1.129, U45.4 (IN_B)
67: DIP1.127, U45.2 (IN_A)
68: DIP1.109, U40.4 (IN_B)
69: DIP1.93, U40.2 (IN_A)
70: DIP1.96, U41.4 (IN_B)
71: DIP1.69, U55.4 (IN_B)
72: DIP1.64, U55.2 (IN_A)
73: DIP1.74, U60.4 (IN_B)
74: DIP1.65, U60.2 (IN_A)
75: DIP1.123, U62.4 (IN_B)
76: DIP1.120, U62.2 (IN_A)
77: DIP1.102, U57.4 (IN_B)
78: DIP1.107, U57.2 (IN_A)
79: DIP1.99, U59.2 (IN_A)
80: DIP1.62, U56.4 (IN_B)
81: DIP1.60, U56.2 (IN_A)
82: DIP1.82, U61.4 (IN_B)
83: DIP1.76, U61.2 (IN_A)
84: DIP1.116, U63.4 (IN_B)
85: DIP1.113, U63.2 (IN_A)
86: DIP1.94, U58.4 (IN_B)
87: DIP1.90, U58.2 (IN_A)
88: DIP1.97, U59.4 (IN_B)
+5V: 5V-REG.OUT, DIP1.5V@1 (5V), DIP1.5V@2 (5V)
GND: 5V-REG.GND, 20V-PWR.2, C3.1, C4.1, C5.1, C7.1, C9.1, C10.1, C11.1, C12.1, C13.1, C19.1, C20.1, C21.1, C22.1, C23.1, C24.1, C25.1, C26.1, C27.1, C28.1, C29.1, C30.1, C31.1, C32.1, C34.1, C35.1, C36.1, C37.1, C38.1, C39.1, C40.1, C41.1, C42.1, C43.1, C44.1, C45.1, C55.1, C56.1, C57.1, C58.1, C59.1, C60.1, C61.1, C62.1, C63.1, DATA.11, DIP1.GND@1 (GND), DIP1.GND@2 (GND), DIP1.GND@3 (GND), DIP1.GND@4 (GND), T1.- (1), T2.- (1), T3.- (1), T4.- (1), T5.- (1), T6.- (1), T7.- (1), T8.- (1), T9.- (1), T10.- (1), T11.- (1), T12.- (1), T13.- (1), T14.- (1), T15.- (1), T16.- (1), T17.- (1), T18.- (1), T19.- (1), T20.- (1), T21.- (1), T22.- (1), T23.- (1), T24.- (1), T25.- (1), T26.- (1), T27.- (1), T28.- (1), T29.- (1), T30.- (1), T31.- (1), T32.- (1), T33.- (1), T34.- (1), T35.- (1), T36.- (1), T37.- (1), T38.- (1), T39.- (1), T40.- (1), T41.- (1), T42.- (1), T43.- (1), T44.- (1), T45.- (1), T46.- (1), T47.- (1), T48.- (1), T49.- (1), T50.- (1), T51.- (1), T52.- (1), T53.- (1), T54.- (1), T55.- (1), T56.- (1), T57.- (1), T58.- (1), T59.- (1), T60.- (1), T61.- (1), T62.- (1), T63.- (1), T64.- (1), T65.- (1), T66.- (1), T67.- (1), T68.- (1), T69.- (1), T70.- (1), T71.- (1), T72.- (1), T73.- (1), T74.- (1), T75.- (1), T76.- (1), T77.- (1), T78.- (1), T79.- (1), T80.- (1), T81.- (1), T82.- (1), T83.- (1), T84.- (1), T85.- (1), T86.- (1), T87.- (1), T88.- (1), U3.3 (GND), U4.3 (GND), U5.3 (GND), U7.3 (GND), U9.3 (GND), U10.3 (GND), U11.3 (GND), U12.3 (GND), U13.3 (GND), U19.3 (GND), U20.3 (GND), U21.3 (GND), U22.3 (GND), U23.3 (GND), U24.3 (GND), U25.3 (GND), U26.3 (GND), U27.3 (GND), U28.3 (GND), U29.3 (GND), U30.3 (GND), U31.3 (GND), U32.3 (GND), U34.3 (GND), U35.3 (GND), U36.3 (GND), U37.3 (GND), U38.3 (GND), U39.3 (GND), U40.3 (GND), U41.3 (GND), U42.3 (GND), U43.3 (GND), U44.3 (GND), U45.3 (GND), U55.3 (GND), U56.3 (GND), U57.3 (GND), U58.3 (GND), U59.3 (GND), U60.3 (GND), U61.3 (GND), U62.3 (GND), U63.3 (GND)
unnamed: DATA.1, DIP1.203
unnamed: DATA.2, DIP1.200
unnamed: DATA.3, DIP1.197
unnamed: DATA.4, DIP1.193
unnamed: T27.+ (2), U3.7 (*OUT_A)
unnamed: T26.+ (2), U3.5 (*OUT_B)
unnamed: T20.+ (2), U4.7 (*OUT_A)
unnamed: T19.+ (2), U4.5 (*OUT_B)
unnamed: T29.+ (2), U5.7 (*OUT_A)
unnamed: T28.+ (2), U5.5 (*OUT_B)
unnamed: DATA.5, DIP1.190
unnamed: DATA.6, DIP1.187
unnamed: T24.+ (2), U7.7 (*OUT_A)
unnamed: T23.+ (2), U7.5 (*OUT_B)
unnamed: DATA.7, DIP1.185
unnamed: DATA.8, DIP1.180
unnamed: T33.+ (2), U9.7 (*OUT_A)
unnamed: T32.+ (2), U9.5 (*OUT_B)
unnamed: T22.+ (2), U10.7 (*OUT_A)
unnamed: T21.+ (2), U10.5 (*OUT_B)
unnamed: T25.+ (2), U11.7 (*OUT_A)
unnamed: T34.+ (2), U11.5 (*OUT_B)
unnamed: T18.+ (2), U12.7 (*OUT_A)
unnamed: T17.+ (2), U12.5 (*OUT_B)
unnamed: T31.+ (2), U13.7 (*OUT_A)
unnamed: T30.+ (2), U13.5 (*OUT_B)
unnamed: DATA.9, DIP1.178
unnamed: DATA.10, DIP1.172
unnamed: T36.+ (2), U19.7 (*OUT_A)
unnamed: T35.+ (2), U19.5 (*OUT_B)
unnamed: T45.+ (2), U20.7 (*OUT_A)
unnamed: T44.+ (2), U20.5 (*OUT_B)
unnamed: T42.+ (2), U21.7 (*OUT_A)
unnamed: T41.+ (2), U21.5 (*OUT_B)
unnamed: T51.+ (2), U22.7 (*OUT_A)
unnamed: T50.+ (2), U22.5 (*OUT_B)
unnamed: T43.+ (2), U23.7 (*OUT_A)
unnamed: T52.+ (2), U23.5 (*OUT_B)
unnamed: T38.+ (2), U24.7 (*OUT_A)
unnamed: T37.+ (2), U24.5 (*OUT_B)
unnamed: T47.+ (2), U25.7 (*OUT_A)
unnamed: T46.+ (2), U25.5 (*OUT_B)
unnamed: T40.+ (2), U26.7 (*OUT_A)
unnamed: T39.+ (2), U26.5 (*OUT_B)
unnamed: T49.+ (2), U27.7 (*OUT_A)
unnamed: T48.+ (2), U27.5 (*OUT_B)
unnamed: T2.+ (2), U28.7 (*OUT_A)
unnamed: T1.+ (2), U28.5 (*OUT_B)
unnamed: T9.+ (2), U29.7 (*OUT_A)
unnamed: T8.+ (2), U29.5 (*OUT_B)
unnamed: T6.+ (2), U30.7 (*OUT_A)
unnamed: T5.+ (2), U30.5 (*OUT_B)
unnamed: T15.+ (2), U31.7 (*OUT_A)
unnamed: T14.+ (2), U31.5 (*OUT_B)
unnamed: T7.+ (2), U32.7 (*OUT_A)
unnamed: T16.+ (2), U32.5 (*OUT_B)
unnamed: T11.+ (2), U34.7 (*OUT_A)
unnamed: T10.+ (2), U34.5 (*OUT_B)
unnamed: T4.+ (2), U35.7 (*OUT_A)
unnamed: T3.+ (2), U35.5 (*OUT_B)
unnamed: T13.+ (2), U36.7 (*OUT_A)
unnamed: T12.+ (2), U36.5 (*OUT_B)
unnamed: T54.+ (2), U37.7 (*OUT_A)
unnamed: T53.+ (2), U37.5 (*OUT_B)
unnamed: T63.+ (2), U38.7 (*OUT_A)
unnamed: T62.+ (2), U38.5 (*OUT_B)
unnamed: T60.+ (2), U39.7 (*OUT_A)
unnamed: T59.+ (2), U39.5 (*OUT_B)
unnamed: T69.+ (2), U40.7 (*OUT_A)
unnamed: T68.+ (2), U40.5 (*OUT_B)
unnamed: T61.+ (2), U41.7 (*OUT_A)
unnamed: T70.+ (2), U41.5 (*OUT_B)
unnamed: T56.+ (2), U42.7 (*OUT_A)
unnamed: T55.+ (2), U42.5 (*OUT_B)
unnamed: T65.+ (2), U43.7 (*OUT_A)
unnamed: T64.+ (2), U43.5 (*OUT_B)
unnamed: T58.+ (2), U44.7 (*OUT_A)
unnamed: T57.+ (2), U44.5 (*OUT_B)
unnamed: T67.+ (2), U45.7 (*OUT_A)
unnamed: T66.+ (2), U45.5 (*OUT_B)
unnamed: T72.+ (2), U55.7 (*OUT_A)
unnamed: T71.+ (2), U55.5 (*OUT_B)
unnamed: T81.+ (2), U56.7 (*OUT_A)
unnamed: T80.+ (2), U56.5 (*OUT_B)
unnamed: T78.+ (2), U57.7 (*OUT_A)
unnamed: T77.+ (2), U57.5 (*OUT_B)
unnamed: T87.+ (2), U58.7 (*OUT_A)
unnamed: T86.+ (2), U58.5 (*OUT_B)
unnamed: T79.+ (2), U59.7 (*OUT_A)
unnamed: T88.+ (2), U59.5 (*OUT_B)
unnamed: T74.+ (2), U60.7 (*OUT_A)
unnamed: T73.+ (2), U60.5 (*OUT_B)
unnamed: T83.+ (2), U61.7 (*OUT_A)
unnamed: T82.+ (2), U61.5 (*OUT_B)
unnamed: T76.+ (2), U62.7 (*OUT_A)
unnamed: T75.+ (2), U62.5 (*OUT_B)
unnamed: T85.+ (2), U63.7 (*OUT_A)
unnamed: T84.+ (2), U63.5 (*OUT_B)
VDD: 5V-REG.IN, 20V-PWR.1, C3.2, C4.2, C5.2, C7.2, C9.2, C10.2, C11.2, C12.2, C13.2, C19.2, C20.2, C21.2, C22.2, C23.2, C24.2, C25.2, C26.2, C27.2, C28.2, C29.2, C30.2, C31.2, C32.2, C34.2, C35.2, C36.2, C37.2, C38.2, C39.2, C40.2, C41.2, C42.2, C43.2, C44.2, C45.2, C55.2, C56.2, C57.2, C58.2, C59.2, C60.2, C61.2, C62.2, C63.2, U3.6 (VDD), U4.6 (VDD), U5.6 (VDD), U7.6 (VDD), U9.6 (VDD), U10.6 (VDD), U11.6 (VDD), U12.6 (VDD), U13.6 (VDD), U19.6 (VDD), U20.6 (VDD), U21.6 (VDD), U22.6 (VDD), U23.6 (VDD), U24.6 (VDD), U25.6 (VDD), U26.6 (VDD), U27.6 (VDD), U28.6 (VDD), U29.6 (VDD), U30.6 (VDD), U31.6 (VDD), U32.6 (VDD), U34.6 (VDD), U35.6 (VDD), U36.6 (VDD), U37.6 (VDD), U38.6 (VDD), U39.6 (VDD), U40.6 (VDD), U41.6 (VDD), U42.6 (VDD), U43.6 (VDD), U44.6 (VDD), U45.6 (VDD), U55.6 (VDD), U56.6 (VDD), U57.6 (VDD), U58.6 (VDD), U59.6 (VDD), U60.6 (VDD), U61.6 (VDD), U62.6 (VDD), U63.6 (VDD)

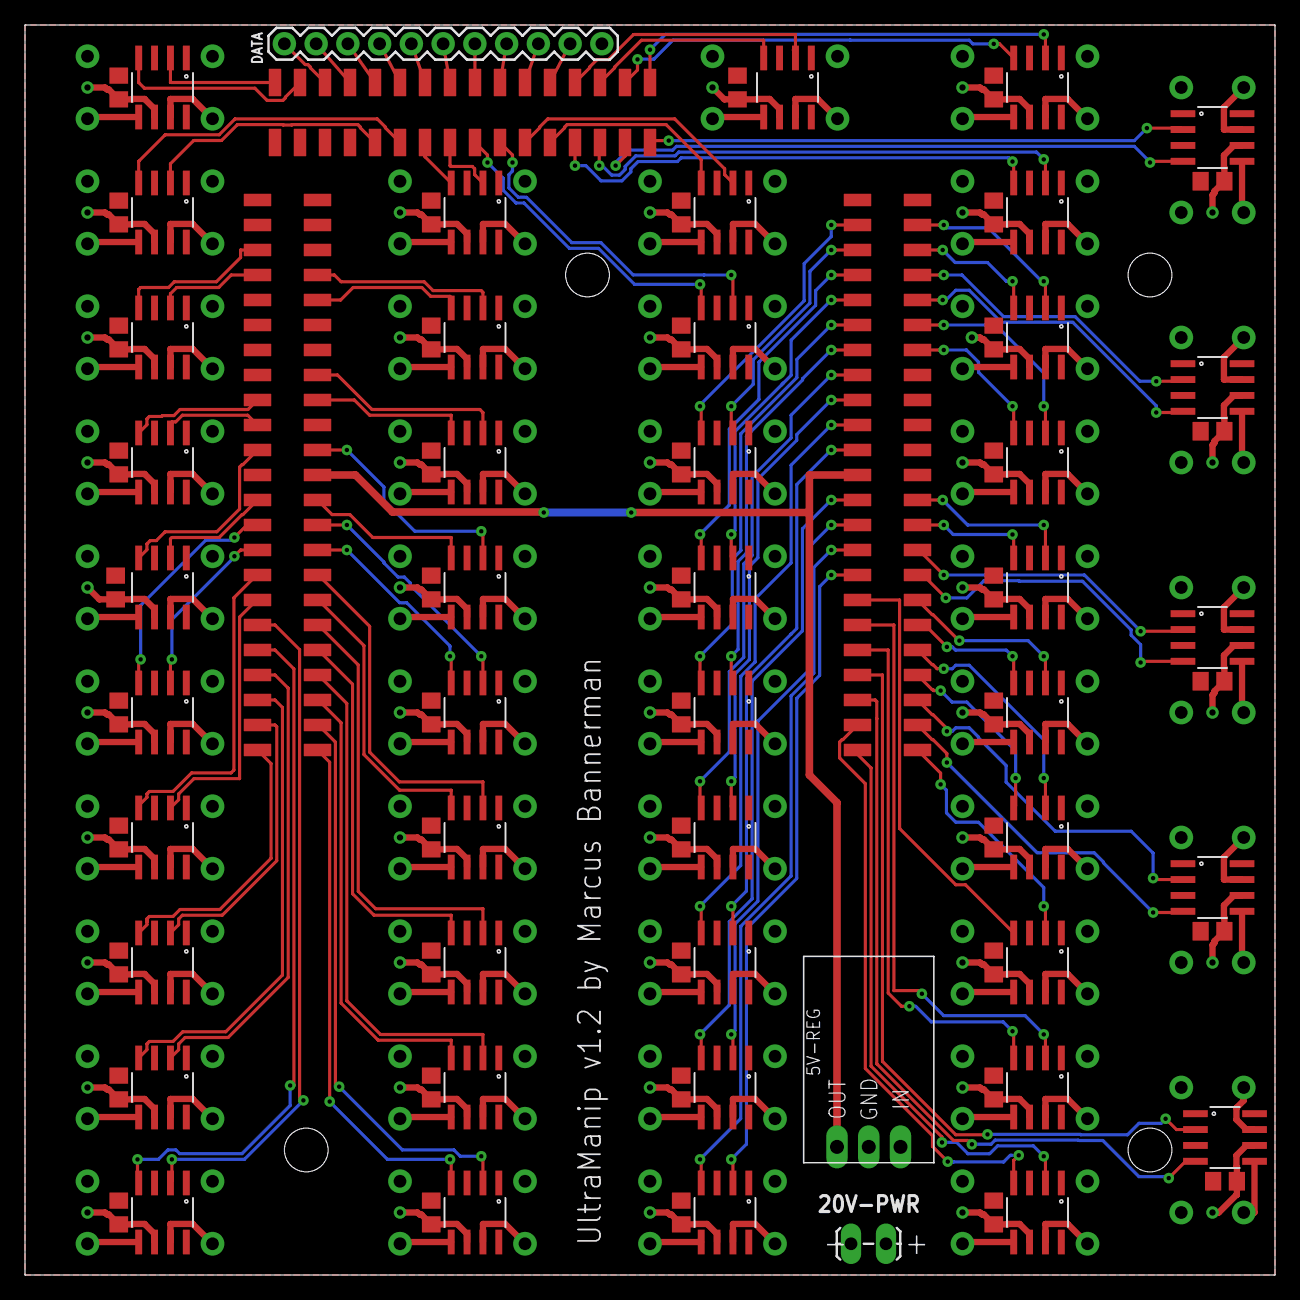
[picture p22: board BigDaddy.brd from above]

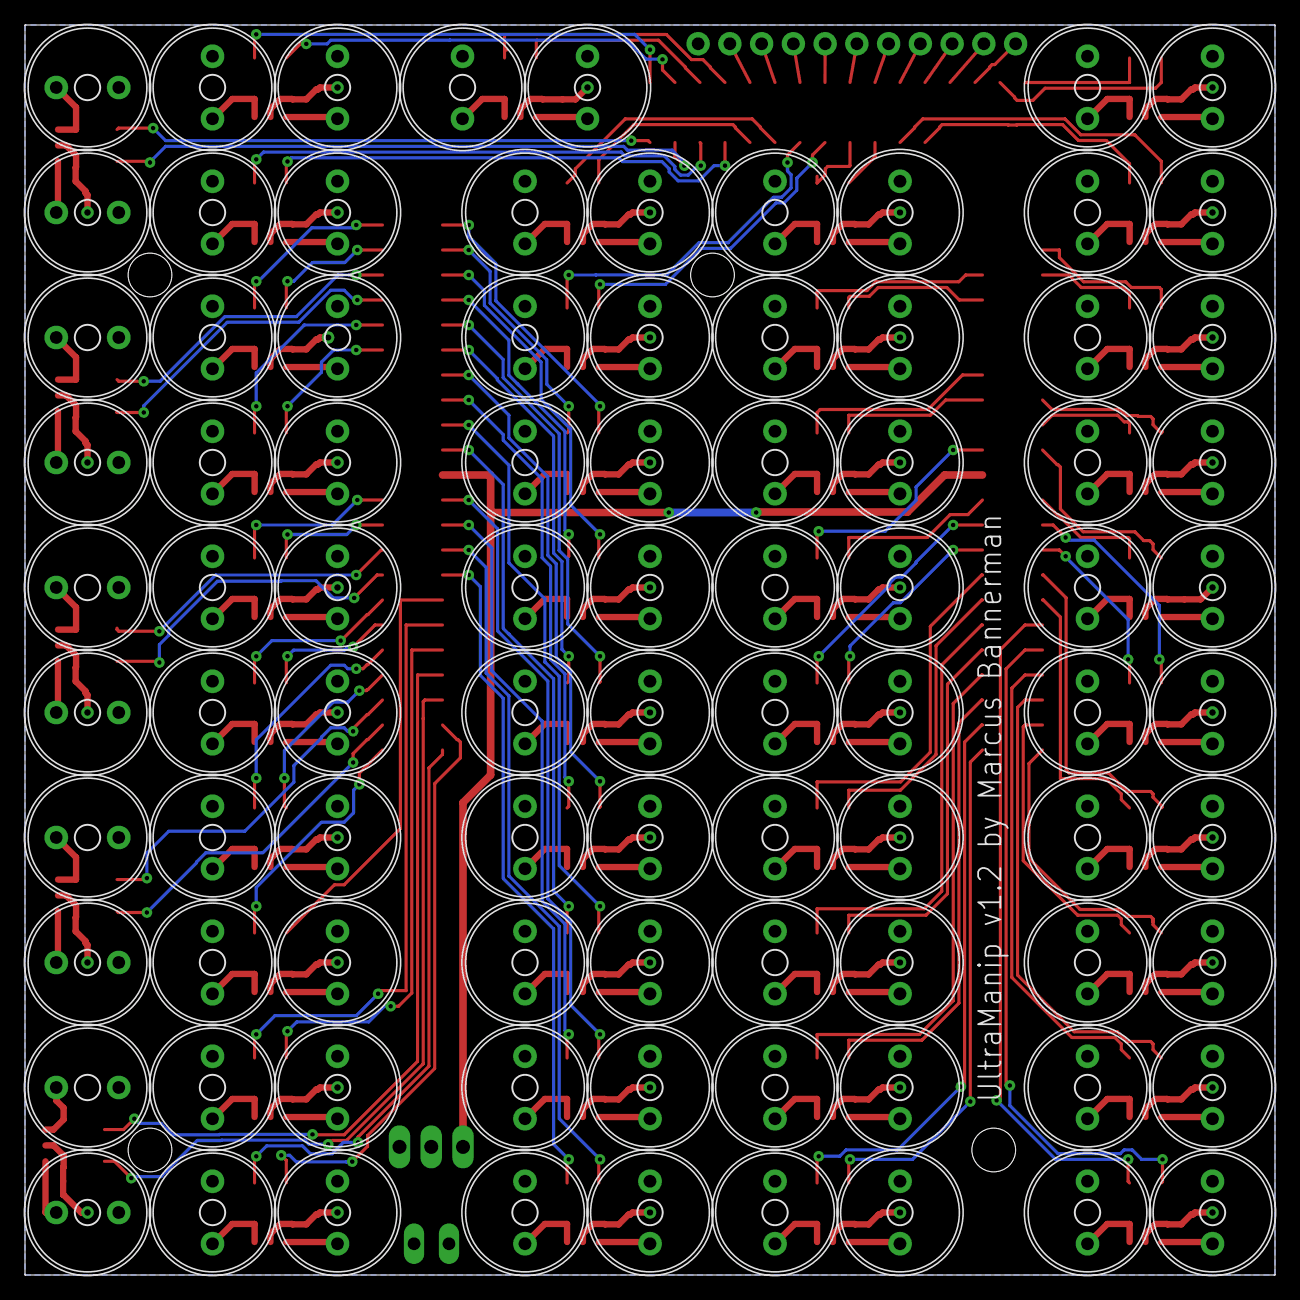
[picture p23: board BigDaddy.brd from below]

Board: 2 copper layers, 100.0 x 100.0 mm, 180 parts (88 on the bottom side), 189 nets.

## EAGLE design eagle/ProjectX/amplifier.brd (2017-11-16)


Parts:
C1, C5, C9, C11, C17, C19, C25, C27: 4.7uF; C0805
C2, C6, C10, C12, C18, C20, C26, C28: 100nF; C0805
D1: LED0603; LED-0603
J1: CONN_02PTH3; 1X02_LONGPADS
R1: 1k; 0805
SV1, SV2: MA20-2W
U1, U2, U5, U6, U9, U10, U11, U12, U17, U18, U19, U20, U25, U26, U27, U28: TC4427COA; SOIC127P600X175-8N

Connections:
GND: C1.2, C2.2, C5.2, C6.2, C9.2, C10.2, C11.2, C12.2, C17.2, C18.2, C19.2, C20.2, C25.2, C26.2, C27.2, C28.2, D1.C, J1.2, SV1.GND, SV1.GND+1, SV2.GND, SV2.GND+1, U1.1 (NC), U1.3 (GND), U2.1 (NC), U2.3 (GND), U5.1 (NC), U5.3 (GND), U6.1 (NC), U6.3 (GND), U9.1 (NC), U9.3 (GND), U10.1 (NC), U10.3 (GND), U11.1 (NC), U11.3 (GND), U12.1 (NC), U12.3 (GND), U17.1 (NC), U17.3 (GND), U18.1 (NC), U18.3 (GND), U19.1 (NC), U19.3 (GND), U20.1 (NC), U20.3 (GND), U25.1 (NC), U25.3 (GND), U26.1 (NC), U26.3 (GND), U27.1 (NC), U27.3 (GND), U28.1 (NC), U28.3 (GND)
unnamed: SV2.2, U2.4 (IN_B)
unnamed: SV1.2, U2.5 (*OUT_B)
unnamed: SV1.4, U1.5 (*OUT_B)
unnamed: SV2.4, U1.4 (IN_B)
unnamed: SV2.3, U1.2 (IN_A)
unnamed: SV2.1, U2.2 (IN_A)
unnamed: SV1.16, U12.5 (*OUT_B)
unnamed: SV1.24, U20.5 (*OUT_B)
unnamed: SV1.8, U6.5 (*OUT_B)
unnamed: SV1.1, U2.7 (*OUT_A)
unnamed: SV1.3, U1.7 (*OUT_A)
unnamed: SV1.7, U6.7 (*OUT_A)
unnamed: SV1.10, U10.5 (*OUT_B)
unnamed: SV1.9, U10.7 (*OUT_A)
unnamed: SV1.11, U9.7 (*OUT_A)
unnamed: SV1.23, U20.7 (*OUT_A)
unnamed: SV2.6, U5.4 (IN_B)
unnamed: SV2.5, U5.2 (IN_A)
unnamed: SV2.8, U6.4 (IN_B)
unnamed: D1.A, R1.1
unnamed: SV2.7, U6.2 (IN_A)
unnamed: SV1.5, U5.7 (*OUT_A)
unnamed: SV1.6, U5.5 (*OUT_B)
unnamed: SV1.15, U12.7 (*OUT_A)
unnamed: SV1.12, U9.5 (*OUT_B)
unnamed: SV2.12, U9.4 (IN_B)
unnamed: SV2.11, U9.2 (IN_A)
unnamed: SV2.10, U10.4 (IN_B)
unnamed: SV2.9, U10.2 (IN_A)
unnamed: SV2.14, U11.4 (IN_B)
unnamed: SV2.13, U11.2 (IN_A)
unnamed: SV2.16, U12.4 (IN_B)
unnamed: SV2.15, U12.2 (IN_A)
unnamed: SV1.13, U11.7 (*OUT_A)
unnamed: SV1.14, U11.5 (*OUT_B)
unnamed: SV2.20, U17.4 (IN_B)
unnamed: SV2.19, U17.2 (IN_A)
unnamed: SV2.18, U18.4 (IN_B)
unnamed: SV1.17, U18.7 (*OUT_A)
unnamed: SV1.18, U18.5 (*OUT_B)
unnamed: SV2.17, U18.2 (IN_A)
unnamed: SV1.19, U17.7 (*OUT_A)
unnamed: SV1.20, U17.5 (*OUT_B)
unnamed: SV2.22, U19.4 (IN_B)
unnamed: SV2.21, U19.2 (IN_A)
unnamed: SV2.24, U20.4 (IN_B)
unnamed: SV2.23, U20.2 (IN_A)
unnamed: SV1.21, U19.7 (*OUT_A)
unnamed: SV1.22, U19.5 (*OUT_B)
unnamed: SV2.28, U25.4 (IN_B)
unnamed: SV2.27, U25.2 (IN_A)
unnamed: SV2.26, U26.4 (IN_B)
unnamed: SV1.25, U26.7 (*OUT_A)
unnamed: SV1.26, U26.5 (*OUT_B)
unnamed: SV2.25, U26.2 (IN_A)
unnamed: SV1.27, U25.7 (*OUT_A)
unnamed: SV1.28, U25.5 (*OUT_B)
unnamed: SV2.30, U27.4 (IN_B)
unnamed: SV2.29, U27.2 (IN_A)
unnamed: SV2.32, U28.4 (IN_B)
unnamed: SV1.31, U28.7 (*OUT_A)
unnamed: SV1.32, U28.5 (*OUT_B)
unnamed: SV2.31, U28.2 (IN_A)
unnamed: SV1.29, U27.7 (*OUT_A)
unnamed: SV1.30, U27.5 (*OUT_B)
VDD: C1.1, C2.1, C5.1, C6.1, C9.1, C10.1, C11.1, C12.1, C17.1, C18.1, C19.1, C20.1, C25.1, C26.1, C27.1, C28.1, J1.1, R1.2, U1.6 (VDD), U1.8 (NC_2), U2.6 (VDD), U2.8 (NC_2), U5.6 (VDD), U5.8 (NC_2), U6.6 (VDD), U6.8 (NC_2), U9.6 (VDD), U9.8 (NC_2), U10.6 (VDD), U10.8 (NC_2), U11.6 (VDD), U11.8 (NC_2), U12.6 (VDD), U12.8 (NC_2), U17.6 (VDD), U17.8 (NC_2), U18.6 (VDD), U18.8 (NC_2), U19.6 (VDD), U19.8 (NC_2), U20.6 (VDD), U20.8 (NC_2), U25.6 (VDD), U25.8 (NC_2), U26.6 (VDD), U26.8 (NC_2), U27.6 (VDD), U27.8 (NC_2), U28.6 (VDD), U28.8 (NC_2)


Board: 2 copper layers, 88.6 x 54.0 mm, 37 parts (1 on the bottom side), 67 nets.

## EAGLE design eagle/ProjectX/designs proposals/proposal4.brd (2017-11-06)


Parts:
C1, C3: 4.7uF; C0805
C2, C4: 100nF; C0805
SV1, SV2: MA20-2W
U1, U2: TC4427COA; SOIC127P600X175-8N

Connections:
GND: C1.2, C2.2, C3.2, C4.2, SV1.1, SV1.2, SV2.1, SV2.2, U1.3 (GND), U2.3 (GND)
unnamed: SV2.34, U2.4 (IN_B)
unnamed: SV1.39, U1.7 (*OUT_A)
unnamed: SV1.37, U1.5 (*OUT_B)
unnamed: SV2.38, U1.4 (IN_B)
unnamed: SV2.40, U1.2 (IN_A)
unnamed: SV2.36, U2.2 (IN_A)
unnamed: SV1.35, U2.7 (*OUT_A)
unnamed: SV1.33, U2.5 (*OUT_B)
VCC: C1.1, C2.1, C3.1, C4.1, SV1.3, SV1.4, SV2.3, SV2.4, U1.6 (VDD), U2.6 (VDD)


Board: 2 copper layers, 100.0 x 80.0 mm, 8 parts (1 on the bottom side), 10 nets.

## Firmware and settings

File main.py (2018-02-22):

# -*- coding: utf-8 -*-

# -------------------------Import Libaries------------------------------------

import constants; import numpy as np; import calc_pressure_field; import time; import algorithms
import transducer_placment; from vti_writer import vti_writer; import phase_algorithms; import scipy.ndimage

# -------------------------Variables to set------------------------------------



##opposite arrays
    
rt = transducer_placment.big_daddy()

ntrans = len (rt)   # Total number of transducers in grid
nt_1 = transducer_placment.direction_vectors(ntrans,[1,0,0]) # nt is the direction vector of each transducer
nt_2 = transducer_placment.direction_vectors(ntrans,[-1,0,0])

sideways_1 = np.copy(rt)
sideways_2 = np.copy(rt)

sideways_1[:,0] = np.add(rt[:,2], -0.05)
sideways_1[:,2] = np.add(rt[:,0], 0.05)

sideways_2[:,0] = np.add(rt[:,2], 0.05)
sideways_2[:,2] = np.add(rt[:,0], 0.05)

rt_both_arrays = np.append(sideways_1, sideways_2, axis=0)
nt_both_arrays = np.append(nt_1, nt_2, axis=0)

#transducer_placment.plot_as_vectors(rt_both_arrays,nt_both_arrays)  # Use to plot the array layout in 3D

rt = rt_both_arrays

nt = nt_both_arrays



#rt = transducer_placment.big_daddy()   # spcing , x nummber, y number of transducers
ntrans = len (rt)   # Total number of transducers in grid

#nt = transducer_placment.direction_vectors(ntrans,[0,0,1]) # nt is the direction vector of each transducer

focus_point = [ 0 , 0 , 0.05 ]

phi_focus = phase_algorithms.phase_find(rt, focus_point[0], focus_point[1], focus_point[2]) # phi is the initial phase of each transducer to focus on a point
phi_signature = phase_algorithms.add_twin_signature(rt, np.copy(phi_focus), 90) # Positions, phases, angle of plane betweem 0 and 180 degrees
#phi_noise = phase_algorithms.phase_random_noise(2, np.copy(phi_signature)) # number is randomness multiplier (0-1)*multiplier scaled between 0 and 2pi

phi = phi_signature

#phi = phase_algorithms.phase_discretize(np.copy(phi))




# ----------------------Setting up output arrays-------------------------------

pcombined = np.zeros ((constants.npoints,constants.npoints,constants.npoints),dtype=complex)

px = np.zeros ((constants.npoints,constants.npoints,constants.npoints), dtype=complex)
py = np.copy(px); pz = np.copy(px)

ux = np.zeros ((constants.npoints,constants.npoints,constants.npoints), dtype=float)
uy = np.copy(ux); uz = np.copy(ux)

pabs = np.zeros ((constants.npoints,constants.npoints,constants.npoints), dtype=float) 
pxabs = np.copy(pabs); pyabs = np.copy(pabs); pzabs = np.copy(pabs)

u = np.zeros ((constants.npoints,constants.npoints,constants.npoints), dtype=float)

height = np.zeros ((constants.npoints,constants.npoints,constants.npoints), dtype=float)

# ----------------------------------------------------------------------------

t0 = time.time()

#p_old = calc_pressure_field.calc_pressure_field(rt, nt, ntrans, phi) # calculate pressure field

t1 = time.time()
p = calc_pressure_field.calc_pressure_field_numpy(rt, nt, ntrans, phi)
t2 = time.time()
print(" ")
print("Numpy pressure calculation took ",round(t2-t1,2), " seconds" )
print(" ")


# -----------------Loop to sum pressure of all transducers---------------------

height = np.multiply(constants.deltaxyz, np.indices([constants.npoints, constants.npoints, constants.npoints])[2]) # 55 times faster
pcombined = np.sum(np.copy(p), axis = 0) 

# -----------------Calculating derrivitive of the pressure field---------------

diff_p = np.gradient(pcombined,constants.deltaxyz)
px = np.copy(diff_p[0]); py = np.copy(diff_p[1]); pz = np.copy(diff_p[2])

# ----------------- Calculating the Gork’ov potential-------------------------

# Calculating absuloute values for the pressure field and its derrivitives
       
pabs   = np.absolute(pcombined)  
pxabs  = np.absolute(px)  
pyabs  = np.absolute(py)  
pzabs  = np.absolute(pz)  

# Calculating Gork’ov potential u (Including gravity)

u = ( np.subtract( np.subtract( np.multiply(np.multiply(2, constants.k1), np.power(pabs, 2) ), 
np.multiply( np.multiply(2, constants.k2), np.add(np.add(np.power(pxabs, 2), np.power(pyabs, 2)), np.power(pzabs, 2) ) ) ),  
np.multiply(constants.p_mass, np.multiply(constants.gravity, np.copy(height)))) ) # Gravity term

# -----------------Calculating derrivitive of Gork’ov potential ---------------

diff_u = np.gradient(u,constants.deltaxyz)
ux = np.copy(diff_u[0]); uy = np.copy(diff_u[1]); uz = np.copy(diff_u[2])

# -----------------Calculating force on particle ---------------

fx = np.copy(-ux); fy = np.copy(-uy); fz = np.copy(-uz)


laplace_u = scipy.ndimage.filters.laplace(u)



# -------------------Creating output images and vtk file----------------------

vti_writer (constants.npoints, pabs, fx, fy, fz, u, laplace_u)


print("For use in paraview: ")
print("Trap point at index ", np.divide(focus_point, constants.deltaxyz), " Away from [0,0,0]")
print("Particle radius in indexes = ", np.divide(np.divide(constants.particle_diamiter,2), constants.deltaxyz))
print(" ")
print("Calculations compleated successfuly")







"""


# ------------Main file but using the analyitical pressure equations-----------

import constants; import numpy as np; from calc_pressure_field import calc_pressure_field
import transducer_placment; from vti_writer import vti_writer; import phase_algorithms; import algorithms;


#rt = transducer_placment.big_daddy()
rt = transducer_placment.array_grid(0.01, 6, 6) 
ntrans = len (rt)
nt = transducer_placment.direction_vectors(ntrans)
phi_focus = phase_algorithms.phase_find(rt,0, 0.02, 0) # phi is the initial phase of each transducer to focus on a point
phi = phase_algorithms.add_twin_signature(rt, np.copy(phi_focus))


################# Wont work now without adding p_abs to the acoustic_potential function in algorithms(invalid index to scalar variable.)
u = np.zeros ((constants.npoints,constants.npoints,constants.npoints), dtype=float)
p_abs = np.zeros ((constants.npoints,constants.npoints,constants.npoints), dtype=float)

x = constants.x; y = constants.y; z = constants.z
gsize = constants.gsize
for xloop in range (0,constants.npoints):
    for yloop in range (0,constants.npoints):
        for zloop in range (0,constants.npoints):
            
            r = [ x  , y , z ]          # Point in space for each itteriation
            u_and_p = algorithms.acoustic_potential(r, rt, phi, nt)
            u[xloop,yloop,zloop] = u_and_p[0] - (constants.p_mass*constants.gravity*(yloop*constants.deltaxyz)) # including potential energy (mass*g*height)
            p_abs[xloop,yloop,zloop] = u_and_p[1]            
                        
            z = z + constants.deltaxyz    # Adding delta to x,y and z
        y = y + constants.deltaxyz
        z = -gsize               # Resetting the value of z to start value for next loop
    x = x + constants.deltaxyz
    y = 0                       # Resetting the value of y to start value for next loop
    z = -gsize                   # Resetting the value of z to start value for next loop
x = -gsize # Initial values of x,y and z in (m) Grid volume
y = 0.00
z = -gsize


diff_u = np.gradient(u,constants.deltaxyz)
ux = np.copy(diff_u[0]); uy = np.copy(diff_u[1]); uz = np.copy(diff_u[2])

# -----------------Calculating force on particle ---------------

fx = np.copy(-ux); fy = np.copy(-uy); fz = np.copy(-uz)

vti_writer (constants.npoints,p_abs,fx,fy,fz,u)

print("Calculations compleated successfuly")


"""

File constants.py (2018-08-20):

# -*- coding: utf-8 -*-

# constants. Config
import math



gsize = 0.02      # Half the length of grid box (m)
deltaxyz = 0.00045    # Distance between points in grid (m)

x = -gsize           # Initial values of x,y and z in (m) Grid volume
y = -gsize
z = -gsize
npoints = int(1 + ((2 * gsize) / deltaxyz)) # Number of points on x y and z axis, plus 1 to index properly


if npoints % 2 == 0:
    print("Number of points is even (No central point exists): ", npoints)
    print("Change the grid size or delta x y z value")
    #exit
else:
    print("Number of points is odd (central point exists): ", npoints)
 

phaseresolution = 1000     # Phase resolution x as in ( 2*pi )/( x ) number of divisions of the phases
p0 = 0.364                  # Amplitude constant 0.364 checked to be correct for our baord
A = 18                 # Peak to peak amplitude
a = 0.0045                  # Piston radius
lamda = 0.00865             # Wavelegnth meters
freq = 40000                # Frequency in Hz
rhoo = 1.2                 # Density of air kg/m^3
rhos = 18.5                 # Density of particle kg/m^3    18.5 Calculated in the lab for white polysterine beads
co = 346                    # Speed of sound in Air m/s
cs = 2600                   # Speed of sound in particle material m/s
particle_diamiter = 0.0042  # Particle diamiter in m


v = (math.pi * particle_diamiter**3)/6.0        # Particle Volume 
p_mass = rhos * v           # particle mass in kg
gravity = -9.81             # m/s^2 negitive as gravity is down \|/

# 4 constants for the Gork’ov potential equation

k1 = ( (1/4) * v * ( ( (1)/((co**2)*(rhoo)) ) - ( (1)/((cs**2)*(rhos)) )))
k2n = (rhoo - rhos)
k2d = (freq**2) * rhoo * (rhoo + 2*rhos)
k2 =  ( (3/4) * v * ( k2n/k2d ) )



#### New constants for gorkov potential

ohmega = freq * math.pi * 2

k = 1 / (rhoo * co**2)
k_p =  1 / (rhos * cs**2)
k_tilda = k_p / k
f_1 = 1 - k_tilda

rho_tilda = rhos / rhoo
f_2 = ( 2* (rho_tilda-1) ) / ( (2*rho_tilda) +1 )

vkpretovel = 1 / (rhoo*ohmega)
vkpre = (1/4) * f_1 *  k
vkvel = (3/8) * f_2 * rhoo
vpvol = v

m1 = vpvol * vkpre
m2 = vpvol * vkvel * (vkpretovel**2)

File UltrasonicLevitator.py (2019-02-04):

#!/usr/bin/python3

from numpy import array as Vector #import the basic vector type
import numpy #Import everything else
import math, cmath

class Transducer(): # Make a new class Transducer    
    def __init__(self, pos, director, phi = 0): 
        #Save the position and director in the new Transducer
        self.pos = pos
        self.director = director
        #Check the director is not [0,0,0]
        length = numpy.linalg.norm(self.director)
        if length == 0:
            raise Exception("Cannot use a zero director!")
        self.director = self.director / length
        self.phi = phi
        self.wavelength = 0.00865
        self.PkToPkA = 18.0
        self.p0 = 0.364 # Amplitude constant for our board
        self.k = 2 * math.pi / self.wavelength
        self.PistonRadius = 0.0045

    #Define the string given if someone tries to "print" a Transducer
    def __str__(self):
        return "Transducer{pos="+str(self.pos)+", dir="+str(self.director)+"}"

    #Give the python code required to create this transducer
    def __repr__(self):
        return "Transducer("+repr(self.pos)+", "+repr(self.director)+")"

    def pressure(self, pos, shift = 0):
        #This calculates the pressure this transducer gives to a
        #position in space.  shift allows you to phase shift the
        #transducer (e.g. to make it appear like time is passing)
        rs = pos - self.pos
        mag_rs = numpy.linalg.norm(rs)
        if mag_rs < 0.001: #If within 1mm of the transducer, don't report the pressure, as its flaky if mag_rs->0
            return 0 + 0j
        else:
            theta = math.acos(numpy.dot(rs, self.director) / mag_rs)
            if theta > math.pi/2: #Ignore values behind the transducer
                return 0j;
            
            exponential =  cmath.exp(1j * (self.phi + self.k * mag_rs + shift) ) / mag_rs
            x = (self.k * self.PistonRadius * math.sin(theta))
            if x < 0.000001: #Take care, as when x->0 then sin(x)/x -> 1
                frac = self.p0 * self.PkToPkA
            else:
                frac = self.p0 * self.PkToPkA * math.sin(x) / x
            return exponential * frac

    def dpdx(self, pos, shift = 0):
        #This is an exact expression for calculating nabla p (gradient
        #of the pressure). This is much faster than getting it
        #numerically.
        
        rs = pos - self.pos
        mag_rs = numpy.linalg.norm(rs)

        if mag_rs < 0.001: # Setting calculated dp/dr on top of transducer to zero.
            return numpy.array([0j, 0j, 0j])
        else:
            rs_hat = rs / mag_rs
            theta = math.acos((numpy.dot(rs, self.director)) / mag_rs)
            if theta > math.pi/2:
                return numpy.array([0j, 0j, 0j]);
            
            exponent_term =  cmath.exp(1j * (self.phi + shift + self.k * mag_rs ) ) / mag_rs
            if theta < 0.0001: # zero angle causes divistion by zero error -> directionality function aproaches 0
                fraction_term =  (self.p0 * self.PkToPkA)
                d_exponential_term_dr = ((rs_hat * 1j * self.k * cmath.exp(1j * (self.phi +shift + self.k * mag_rs)) ) / (mag_rs))  -  ((cmath.exp(1j*(self.phi + shift + self.k * mag_rs)) * rs_hat) / (mag_rs**2))
                return fraction_term * d_exponential_term_dr
            else:
                fraction_term =  self.p0 * self.PkToPkA * math.sin(self.k * self.PistonRadius * math.sin(theta)) /  (self.k * self.PistonRadius * math.sin(theta))
                d_exponential_term_dr = rs_hat * 1j * self.k * cmath.exp(1j * (self.phi + shift + self.k * mag_rs)) / mag_rs - cmath.exp(1j * (self.phi + shift + self.k * mag_rs)) * rs_hat / mag_rs**2
                numerator = self.p0 * self.PkToPkA * math.sin(self.k * self.PistonRadius * math.sin(theta))
                denominator =  self.k * self.PistonRadius * math.sin(theta)
                d_denominator_dr = self.k * self.PistonRadius * (-numpy.dot(rs_hat, self.director)) / math.sqrt(1 - numpy.dot(rs_hat, self.director)) * (self.director - rs_hat * numpy.dot(self.director, rs_hat)) / mag_rs
                d_numerator_dr = self.p0 * self.PkToPkA * math.cos(self.k * self.PistonRadius * math.sin(theta)) * d_denominator_dr
                d_fraction_dr = (d_numerator_dr * denominator - numerator * d_denominator_dr) / denominator**2
                return (d_fraction_dr * exponent_term) + (fraction_term * d_exponential_term_dr)

from typing import List

class Particle:
    #This class represents a single particle
    
    def __init__(self, pos, mass, diameter):
        self.position = pos
        self.mass = mass
        self.diameter = diameter
        self.volume = math.pi * self.diameter**3 / 6.0        # Particle Volume
        self.density = self.mass / self.volume
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

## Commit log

2017-10-14 Fixing equation typo in phifind (missing bracket) still check if equation needs to be divided by pi or not (comment in code)
    [main.py, phifind.py]
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2017-10-20 Fixed potential energy of particle being the wrong sign (previously potential energy was going down with height which is wrong)
    [constants.py, main.py]
2017-10-20 Fixed freq to 40khz
    [fmq.v]
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2017-10-27 More work
    [Amplifier.brd, Amplifier.sch]
2017-10-27 Fixed some errors in the sin_theta derrivation
    [differentiation_algorithms.py]
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2017-11-02 Board update
    [Amplifier.brd, Amplifier.sch]
2017-11-07 Some work on the final design
    [amplifier.brd, amplifier.sch, proposal1.brd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]
2017-11-07 More work on the 32 bit board
    [amplifier.brd, amplifier.sch]
2017-11-07 Added a finished board
    [amplifier.brd, amplifier.sch]
2017-11-16 Finished the small amplifier board
    [amplifier.brd, amplifier.sch]
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2017-11-17 Fixed bug where deletions cant be out of order
    [code_testing.py]
2017-11-21 Fixed circle co-ordinate funtion to take any division and any radius. Now outputs a numpy array of x and y coordinates
    [algorithms.py, code_testing.py, constants.py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]
2017-11-24 Some work on a transducer board
    [transducer.brd, transducer.sch]
2017-11-24 Finished the 32 transducer board
    [transducer.brd, transducer.sch]
2017-11-29 Fixed some errors in the FPGA package, and added a SMT variant for the big board
2017-11-29 Start on the big one
    [BigDaddy.brd, BigDaddy.sch]
2017-11-30 Working on the big board
    [BigDaddy.brd, BigDaddy.sch]
2017-11-30 Layout of transducers complete, need to add connectors, power, and then route everything
    [BigDaddy.brd, BigDaddy.sch]
2017-11-30 Some fixes to placement
    [BigDaddy.brd, BigDaddy.sch]
2017-11-30 Ready to route signal traces
    [BigDaddy.brd, BigDaddy.sch]
2017-12-01 More work on the board
    [BigDaddy.brd, BigDaddy.sch]
2017-12-01 Routed 16 channels
    [BigDaddy.brd, BigDaddy.sch]
2017-12-01 Netted up all the remaining amplifiers, need to route and net the FPGA pins to the amplifiers
    [BigDaddy.brd, BigDaddy.sch]
2017-12-01 About 40% complete wiring of signals
    [BigDaddy.brd, BigDaddy.sch]
2017-12-01 Still routing traces
    [BigDaddy.brd, BigDaddy.sch]
2017-12-01 About 80% complete routing
    [BigDaddy.brd, BigDaddy.sch]
2017-12-01 More work on routing
    [BigDaddy.brd]
2017-12-01 Nearly done!
    [BigDaddy.brd, BigDaddy.sch]
2017-12-03 Minor revision to add ground to the data port
    [BigDaddy.brd, BigDaddy.sch]
2017-12-08 Slight improvements to the board, incase we need a new version in the future
    [BigDaddy.brd]
2017-12-15 Restored the eagle work to the last working copy
    [Amplifier.brd, Amplifier.sch, amplifier.brd]
2017-12-15 Reversed all of Nialls rampage through the circuit diagrams, also numbered the transducers in eagle so we can easily export positions
    [2nddesign.brd, 2nddesign.sch, BigDaddy.brd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]
2017-12-16 Numbering T29
    [BigDaddy.brd, BigDaddy.sch]
2017-12-16 Fixed the circle co-ordinate algorithm
    [algorithms.py]
2017-12-17 Fixes for running on windows
    [connect.py]
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2017-12-18 Fixed the error on the connect.py and removed the extra connect in the FPGA folder moved the running function to algorithms
    [algorithms.py, connect.py]
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2017-12-19 corrected a wrong print
    [run_board.py]
2018-01-10 Added ability to calculate the potential field analytically, this has revieled errors in the previous way this was calculated. This will need to be investigated. Algorithms currently holding the anal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
    [algorithms.py, constants.py, vti_writer.py]
2018-01-11 Fixed problem wiht pressure calculation on top of a transducer and when the angle was 0.(may need looked into )
    [algorithms.py, constants.py]
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2018-01-15 Particle simulation constatns problem fixed
    [constants.py, particle_simulation.py]
2018-01-17 Added locations file
    [locations.xlsx, phase.xlsx]
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2018-01-28 Changes to main trying to de-bug the main clacluation of the fields
    [algorithms.py, differentiation_algorithms.py, main.py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]
2018-01-28 Fixed assignment errors in the main file
    [main.py, phase_algorithms.py]
2018-01-28 small changes
    [locations.xlsx]
2018-01-28 Figuring out problems with the main code
    [algorithms.py, main.py]
2018-01-30 Added a new way to calculate the field using numpy so the calculations are roungly 45 times faster than the previous itteration
    [locations.xlsx]
2018-01-30 Fixed Stupid mistake in twin signature where half the transducers were set back to zero .... duuuhh
    [constants.py, main.py, phase_algorithms.py]
2018-01-30 Adding noise to the main function
    [main.py, phase_algorithms.py]
2018-02-07 Now have the Lolin32 lite board working as the USB uart, on to removing glitches
    [UltraManipController.ino, connect.py, fmq.v]
2018-02-09 I now have output power modulation working correctly, all FPGAs need reprogramming
    [connect.py, demo.py, fmq.v]
2018-02-09 Fixed the stupid way that the transducer positon and direction vectors are stored in all files
    [algorithms.py, calc_pressure_field.py, phase_algorithms.py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]
2018-02-10 changed the co-ordinate system so z is up and fixed the inconsistencies with the co-ordinate system in python and in the parawiew files
    [calc_pressure_field.py, constants.py, main.py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]
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2018-02-15 changed to the demo and algorithms --fix needed on angle algorithm
    [algorithms.py, demo.py, phase_algorithms.py]
2018-02-15 Fixed angle problems and added the laplacian of U to the output files (Traps are minima)
    [algorithms.py, constants.py, main.py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]
2018-02-22 Fixed stuid error with taking the edge of the matrix instead of the middle!
    [calc_pressure_field.py, constants.py, force_calc.py]
2018-02-22 Fixed problem with force and potential plotting and working on particle simulation
    [algorithms.py, constants.py, force_calc.py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]
2018-03-01 Removed buzzer mode, as the haptic mode is really how this should be done now, also set the output DAC power to full (256) for other modes
    [check.py, demo.py]
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2018-03-02 Error in the volume calc
    [constants.py, particle_simulation.py]
2018-03-02 Working on particle sim (Wrong direction for gravity after convention change)
    [particle_simulation.py]
2018-03-03 Fixed broken gorkov by implamenting a new method of calculation
    [calc_pressure_field.py, constants.py, force_calc.py]
2018-03-06 Fixed the constants to match our real array
    [constants.py]
2018-03-06 3D flod fill works but recursion problems
    [flood_fill.py]
2018-03-21 Work on fill not working at all
    [constants.py, flood_fill_region.py]
2018-03-23 Fixed rollover bug for 2D data so that now works
    [fill_algorithms.py, force_calc.py]
2018-03-31 Added file to be able to change heights without editing the main file too much vti_writer had a typo that is fixed and the forces output now has the correct origin
    [fill_algorithms.py, fill_algorithms_changing_heights.py, vti_writer.py]
2018-04-10 Found stuid bug that was breaking the height checking algorithm
    [constants.py, demo.py, fill_algorithms.py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]
2018-05-25 Added the moddeling files including the metal profiles
    [Accurate 30 mm profile.SLDPRT, Assembly of frame.SLDASM, Board and transducers.SLDASM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]
2018-08-21 FPGA update to a new baud for stability in communication
    [fmq.v]
2018-09-12 Adding Nialls board files
    [Driver_Board_Niall.brd, Driver_Board_Niall.sch]
2018-09-13 Work in progress driver board
    [Driver_Board_Niall.brd, Driver_Board_Niall.sch]
2018-09-15 Eagle work- niall
    [Driver_Board_Niall.brd, Driver_Board_Niall.sch]
2018-09-16 Niall bord edits
    [Driver_Board_Niall.brd, Driver_Board_Niall.sch]
2018-09-17 Niall Board layout first attempt
    [Driver_Board_Niall.brd, Driver_Board_Niall.sch]
2018-09-18 niall's crap board
    [Driver_Board_Niall.brd]
2018-09-18 Nialls slightly better board atempt 2
    [Driver_Board_Niall.brd, Driver_Board_Niall.sch]
2018-09-20 Nialls boards
    [Driver_Board_Niall.brd, Driver_Board_Niall.sch]
2018-09-20 Nialls's boards
    [BigDaddy.brd, Driver_Board_Niall.brd, Driver_Board_Niall.sch]
2018-09-22 Niall board edits
    [Driver_Board_Niall.brd, Driver_Board_Niall.sch]
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2018-09-23 Niall's work in progress board
    [Driver_Board_Niall.brd, Driver_Board_Niall.sch]
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2018-09-25 Nialls board is ace
    [Driver_Board_Niall.brd, Driver_Board_Niall.sch]
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2018-09-29 New transducer board and leds added
    [Driver_Board_Niall.brd, Driver_Board_Niall.sch, Transducer_board_niall.sch]
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2018-10-02 Niall new board stuff
    [Driver_Board_Niall.brd, Driver_Board_Niall.sch, Transducer_board_niall.sch]
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2018-10-06 Niall Boards new layout that should slot together
    [Driver_Board_Niall.brd, Driver_Board_Niall.sch, Transducer_board_niall.brd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]
2018-10-06 Added capasitors to inputs
    [Driver_Board_Niall.brd, Driver_Board_Niall.sch]
2018-10-06 Niall board more work
    [Driver_Board_Niall.brd, Driver_Board_Niall.sch, Transducer_board_niall.brd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]
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2018-10-07 More DRC fixes
    [Driver_Board_Niall.brd]
2018-10-07 More DRC fixes, just about all done
    [Driver_Board_Niall.brd, Driver_Board_Niall.sch]
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2018-10-07 fixed some issues on the driver
    [Driver_Board_Niall.brd]
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2018-10-09 Niall board better wiring
    [Transducer_board_niall.brd, Transducer_board_niall.sch]
2018-10-10 Fixed top right section of board
    [Transducer_board_niall.brd]
2018-10-10 Transducer board small changes
    [Transducer_board_niall.brd, Transducer_board_niall.sch]
2018-10-10 Niall driver board finished draft 1
    [Driver_Board_Niall.brd, Driver_Board_Niall.sch, Transducer_board_niall.brd]
2018-10-10 Niall DRC errors fixed
    [Driver_Board_Niall.brd]
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2018-10-11 Transducer board in finished state
    [Transducer_board_niall.brd, Transducer_board_niall.sch]
2018-10-12 V0 of driver board needs checked
    [Driver_Board_Niall.brd, Driver_Board_Niall.sch]
2018-10-12 New transducer numbering start
    [Transducer_board_niall.brd, Transducer_board_niall.sch]
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2018-10-12 Just spacing traces a little better if I can
    [Driver_Board_Niall.brd]
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2018-10-13 Version 0 Niall's boards finished design... maybe
    [Driver_Board_Niall.brd, Driver_Board_Niall.sch, Transducer_board_niall.brd]
2018-10-13 Finished driver board - maybe
    [Driver_Board_Niall.brd, Driver_Board_Niall.sch]
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2018-10-15 Transducer board tidied up a bit and submitted
    [Transducer_board_niall.brd]
2019-02-04 fixed error in tests (sys.potential -> sys.Gorkov_potential)
    [UltrasonicLevitator.py]

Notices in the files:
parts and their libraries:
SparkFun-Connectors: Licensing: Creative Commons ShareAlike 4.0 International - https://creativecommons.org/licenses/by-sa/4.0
